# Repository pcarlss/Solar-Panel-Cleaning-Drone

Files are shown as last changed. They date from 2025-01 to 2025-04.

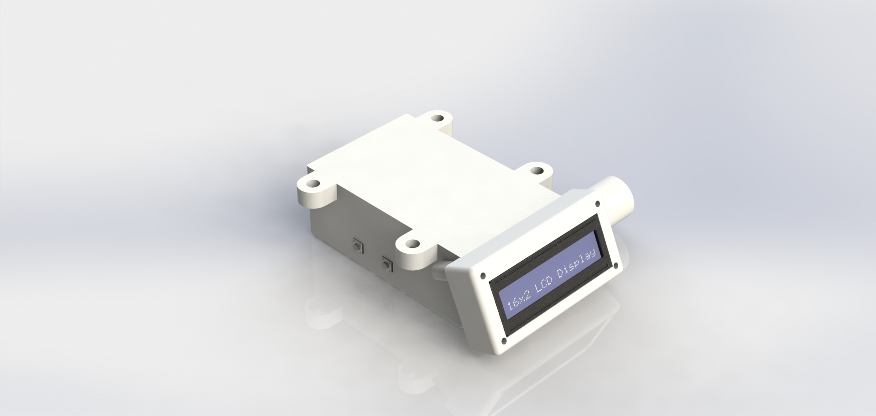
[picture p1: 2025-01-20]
FreeCad/mounting-assembly/Asmbly Render.JPG

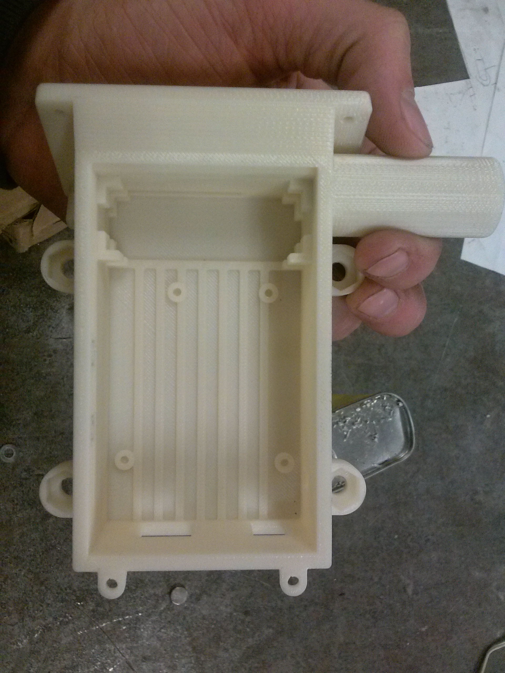
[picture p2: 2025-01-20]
FreeCad/mounting-assembly/Renderings/0404142058d.jpg

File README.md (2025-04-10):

# Solar Panel Cleaning Drone
Drone system developed by a team of 7 Concordia University students to transport and deploy a cleaning bot for efficient rooftop solar panel maintenance.

# Overview
This project is developed by a team of seven students from Concordia University, consisting of five Aerospace Engineering students and two Computer Engineering students. Our goal is to design and develop an autonomous system that utilizes a drone to transport and deploy a cleaning bot for rooftop solar panels. The drone delivers the cleaning bot to the rooftop, where it automatically cleans the solar panels, ensuring maximum efficiency by removing dust and debris. The project involves a combination of drone navigation, robotic automation, and sensor integration to create a fully autonomous cleaning solution.

# Members

## Aerospace Engineering
Our team of Aerospace Engineering students brings a wealth of knowledge and expertise to the project:
- **Aidan Mulrooney Gélinas**
- **Aysenur Kocak**
- **Nadim Zreik**
- **Oumaima Hida**
- **Raad Haider**

## Computer Engineering
Our Computer Engineering students are instrumental in the software and automation aspects:
- **Philip Carlsson-Coulombe**
- **Qian Yi Wang**

# Videos and Images
## Rover Simulation
rover_mission
## Drone Test Flight
ezgif-7473bbbd5976de (1)
## Cads
ISO_FINAL


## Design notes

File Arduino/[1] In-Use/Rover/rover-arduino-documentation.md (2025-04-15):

# Rover Arduino Documentation

## Pin Connection Guide

### Motor Pins
- Left Motor:
  - PWM: D9
  - Direction 1: D8
  - Direction 2: D7
- Right Motor:
  - PWM: D10
  - Direction 1: D11
  - Direction 2: D12
- Cleaning Motor:
  - Enable: D13

### Limit Switch Pins (CD4051B Multiplexer)
- Selector 0: D2
- Selector 1: D3
- Selector 2: D4
- Output: D5

### IMU (ICM-20948) I2C Pins
- SDA: A4
- SCL: A5

### Rotary Encoders
- Left Encoder:
  - Channel A: D2
  - Channel B: D3
- Right Encoder:
  - Channel A: D4
  - Channel B: D5

### Radio Control (nRF24L01)
- CE: D6
- CSN: D7

## Function Documentation

### Core Functions
- `setup()`: Initializes all hardware components including motors, encoders, IMU, and radio communication.
- `loop()`: Main program loop that handles state machine, sensor updates, and motor control.
- `updateData()`: Updates all sensor readings and system state.
- `updatePosition()`: Calculates current position based on encoder and IMU data.

### Motor Control
- `stopMotors()`: Stops all motors safely.
- `updateMotors()`: Updates motor speeds based on PID control.
- `setTrajectory(float linearVelocity, float turnRate)`: Sets desired linear velocity and turn rate.

### Sensor Management
- `getIMUData()`: Reads and processes IMU data.
- `performIMUCalibration()`: Performs IMU calibration sequence.
- `updateLimitSwitches()`: Updates limit switch states using multiplexer.
- `getLimitSwitchPositions()`: Returns current limit switch states.

### Encoder Functions
- `encoderISR_L()`: Interrupt service routine for left encoder.
- `encoderISR_R()`: Interrupt service routine for right encoder.
- `getLinearVelocity()`: Calculates current linear velocity from encoder data.

### Navigation Functions
- `makeDecision()`: Main decision-making function implementing the state machine.
- `searchForCorner()`: Implements corner search behavior.
- `cleanOuterLoop()`: Handles outer loop cleaning behavior.
- `cleanInnerLoops()`: Handles inner loop cleaning behavior.
- `followEdge()`: Implements edge following behavior.
- `followInnerPath()`: Implements inner path following behavior.

### Helper Functions
- `calculatePID()`: Implements PID control algorithm.
- `computeTravel()`: Calculates travel distance and direction.
- `mapInnerPath()`: Calculates inner cleaning path parameters.
- `calculateDistance()`: Calculates distance between two points.

## Setup Instructions

1. Hardware Setup:
   - Connect all motors to their respective pins
   - Connect limit switches through the CD4051B multiplexer
   - Connect IMU via I2C
   - Connect rotary encoders
   - Connect nRF24L01 radio module

2. Software Setup:
   - Install required libraries:
     - Wire.h (built-in)
     - PID_v1.h
     - ICM_20948.h
     - SPI.h (built-in)
     - nRF24L01.h
     - RF24.h

3. Calibration:
   - The system will automatically perform IMU calibration on startup
   - Keep the rover stationary during calibration
   - Calibration takes approximately 5 seconds

4. Operation:
   - Power on the rover
   - Wait for initialization to complete
   - Use the controller to start/stop the cleaning operation
   - The system will automatically handle the cleaning sequence

## Safety Features
- Emergency stop on radio signal loss
- Limit switch protection
- Motor current monitoring
- Automatic stop on error conditions

## Troubleshooting
1. If motors don't respond:
   - Check motor connections
   - Verify PWM pins are correctly connected
   - Check motor driver power supply

2. If IMU fails to initialize:
   - Check I2C connections
   - Verify IMU power supply
   - Ensure correct I2C address

3. If limit switches don't work:
   - Check multiplexer connections
   - Verify switch wiring
   - Test individual switches

4. If radio communication fails:
   - Check CE and CSN connections
   - Verify radio module power supply
   - Ensure correct address matching with controller

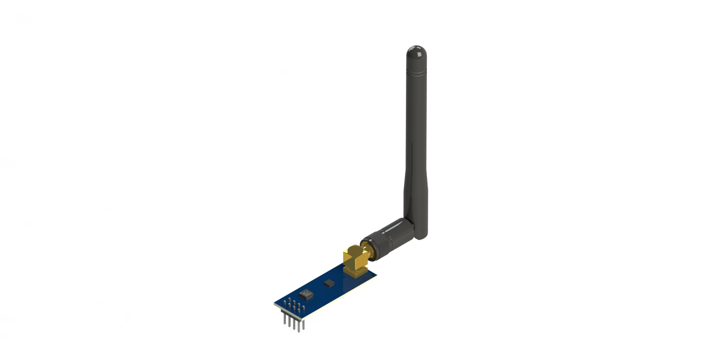
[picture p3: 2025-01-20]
FreeCad/nrf24l01/render/render.png

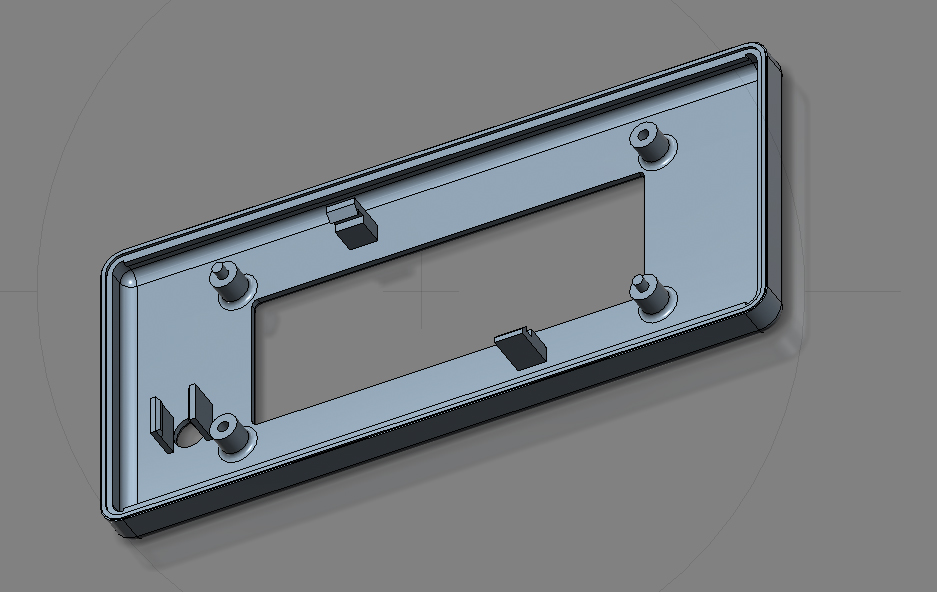
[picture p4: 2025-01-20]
FreeCad/1602_cover/Renderings/LCD_1602_box_03.jpg

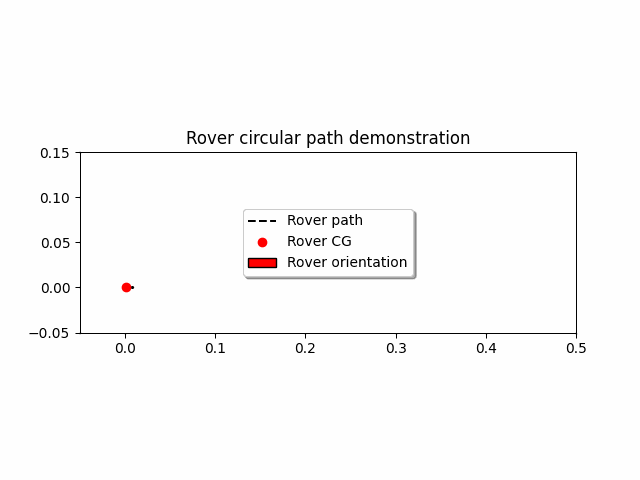
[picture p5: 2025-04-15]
Simulations/Rover-Simulation/movement.gif

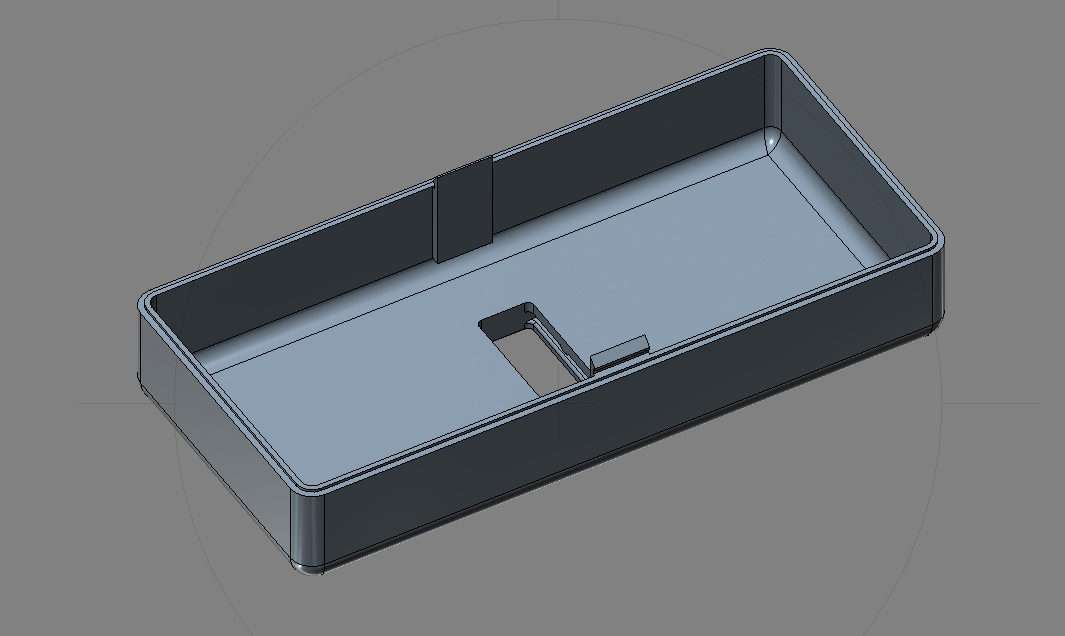
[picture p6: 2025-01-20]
FreeCad/1602_cover/Renderings/LCD_1602_box_04.jpg

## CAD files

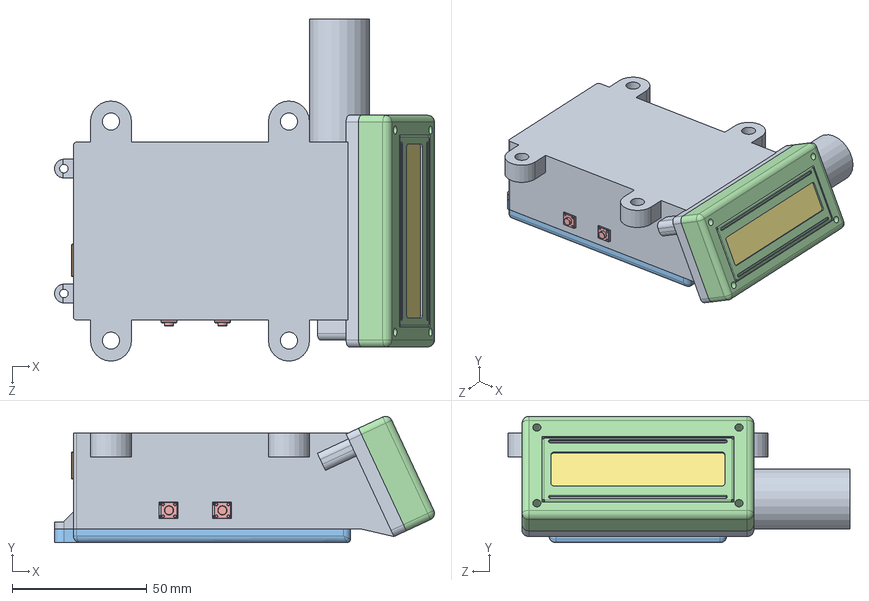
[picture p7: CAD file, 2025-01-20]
FreeCad/mounting-assembly/LCD and Arduino Mount ASMBLY.SLDASM
141.0 x 46.9 x 127.0 mm
Arduino Box
pcbboard
16pin_header__
lcd window
backlight
conductor x 2
liquid crystal grabcad
smt_resistor222 x 6
smt_resistor101 x 2
Arduino Box Lid
LCD Cover
tactileswitch-short x 2

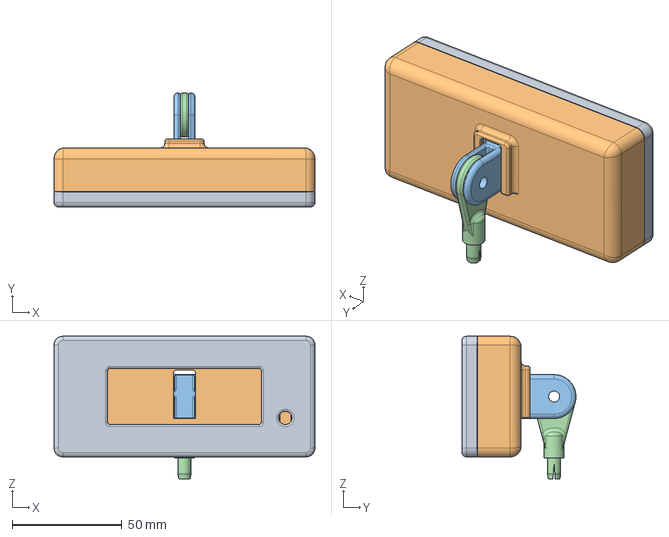
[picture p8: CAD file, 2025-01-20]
FreeCad/1602_cover/LCD-1602.stp
119.0 x 52.0 x 65.0 mm

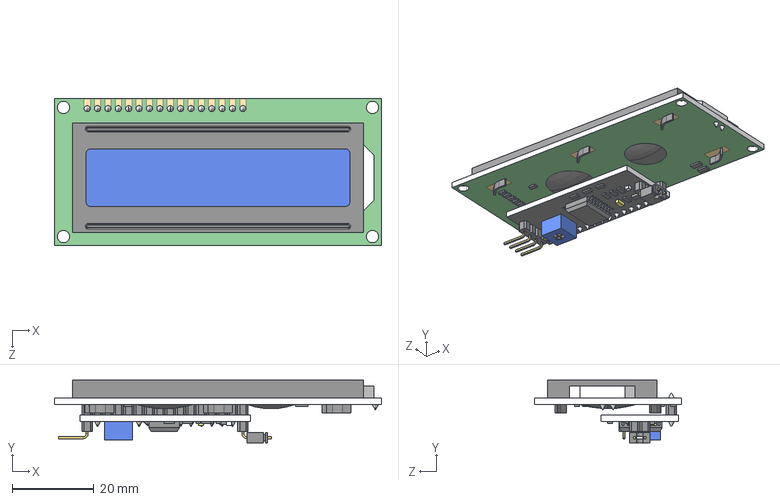
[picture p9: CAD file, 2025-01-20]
FreeCad/1602_model/LCD_I2C_1602.STEP
80.0 x 15.4 x 36.0 mm

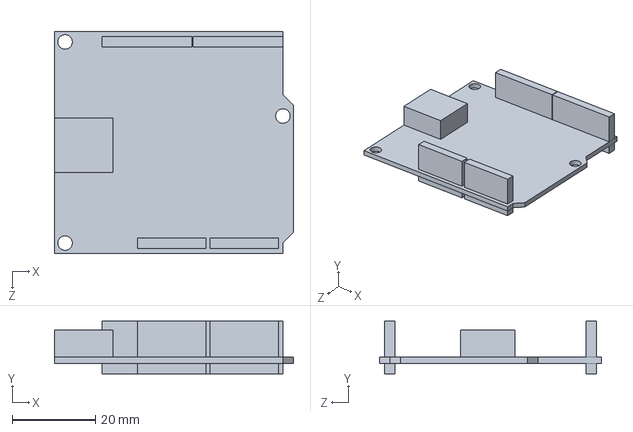
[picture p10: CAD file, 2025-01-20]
FreeCad/usb-host-shield/USBHostShield.SLDPRT
57.3 x 12.6 x 53.3 mm

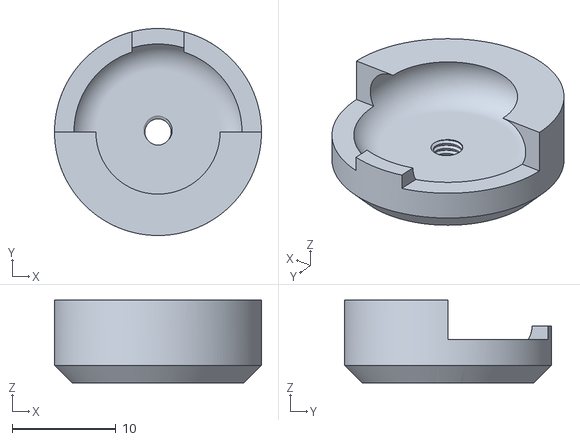
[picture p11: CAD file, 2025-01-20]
FreeCad/xbox-humbstick-extension/threaded_connector.stl
20.0 x 20.0 x 8.00

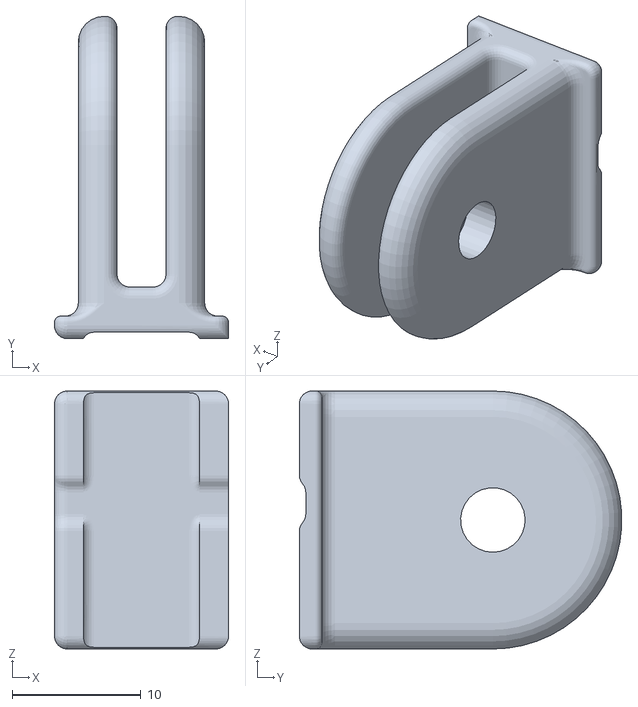
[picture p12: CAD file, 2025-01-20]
FreeCad/1602_cover/LCD-1602_holder-1.stl
13.5 x 25.0 x 20.0

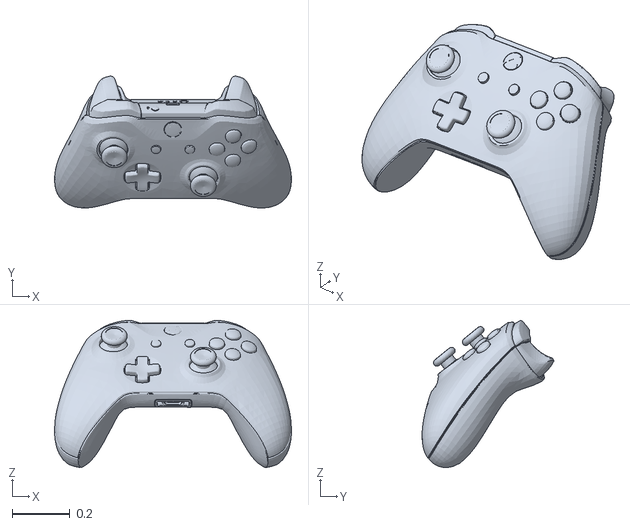
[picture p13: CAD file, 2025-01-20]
FreeCad/ImageToStl.com_white xbox controller.stl
0.824 x 0.459 x 0.512

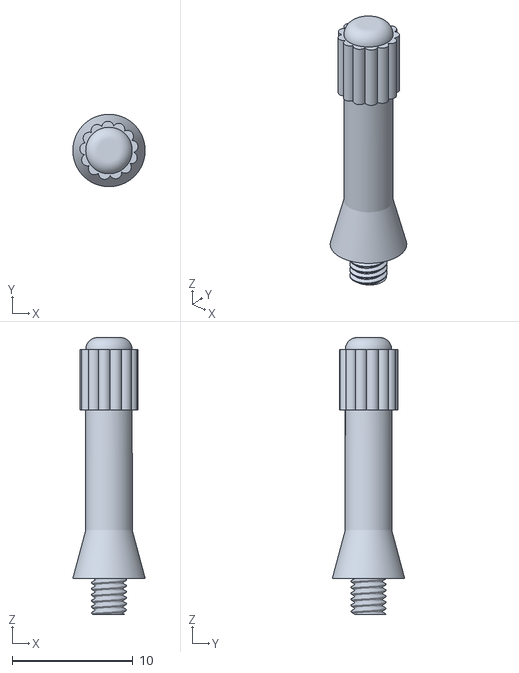
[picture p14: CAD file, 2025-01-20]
FreeCad/xbox-humbstick-extension/stick_short.stl
6.00 x 6.00 x 23.0

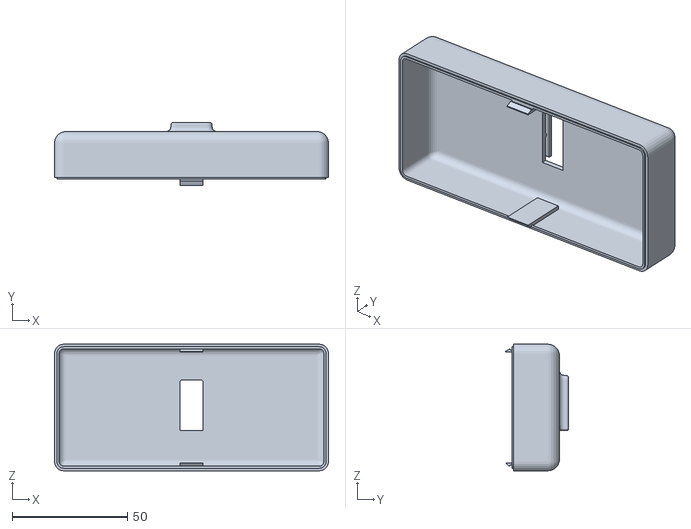
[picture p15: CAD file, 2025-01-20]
FreeCad/1602_cover/LCD-1602_back.stl
119.0 x 27.5 x 55.0

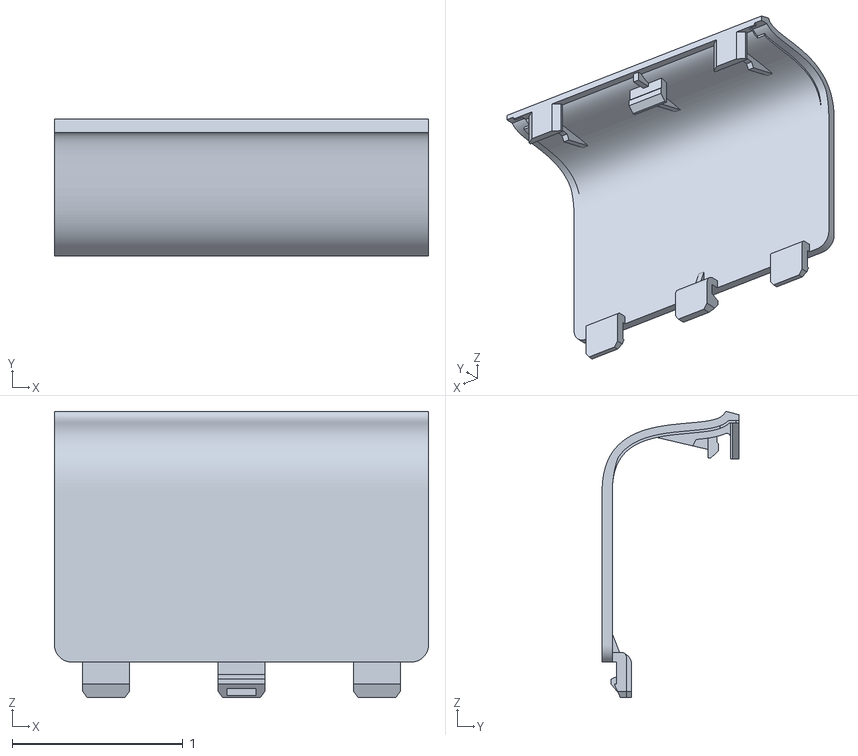
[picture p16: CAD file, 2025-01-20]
FreeCad/Xbox_One_Controller_Battery_Cover_-_Standard.stl
2.19 x 0.8 x 1.68

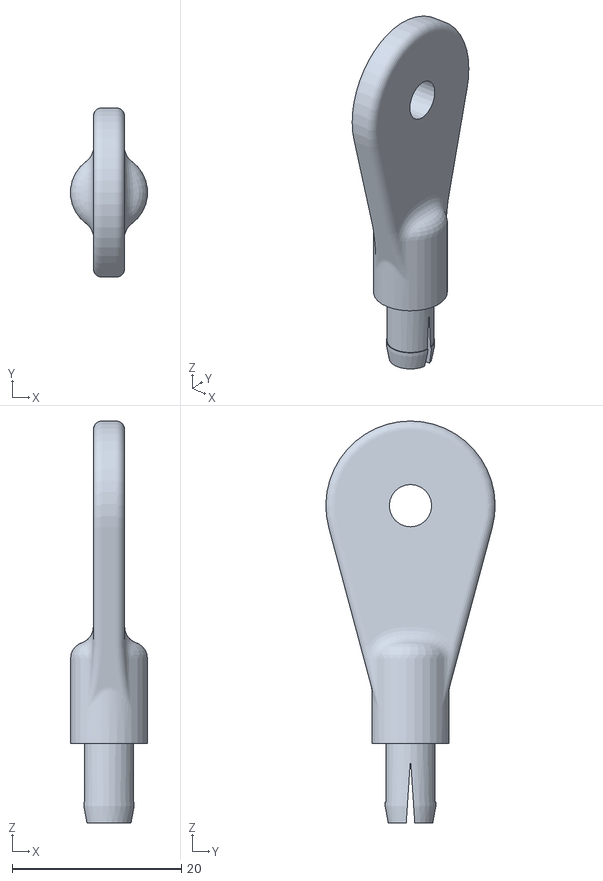
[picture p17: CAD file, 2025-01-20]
FreeCad/1602_cover/LCD-1602_holder-2.stl
9.07 x 20.0 x 47.5

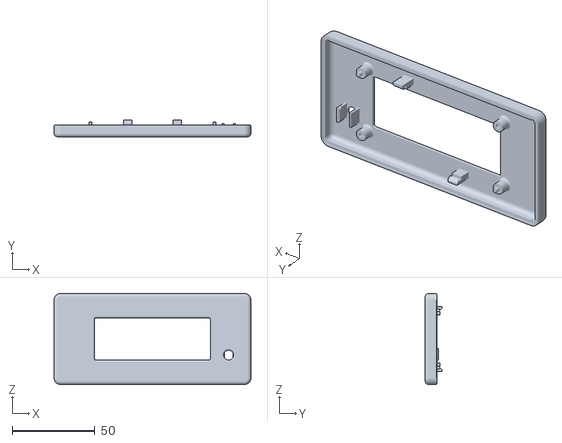
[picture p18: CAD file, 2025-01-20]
FreeCad/1602_cover/LCD-1602_front.stl
119.0 x 10.0 x 55.0

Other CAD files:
FreeCad/ControllerV1.FCStd
FreeCad/1602_cover/LCD-1602.f3d
FreeCad/1602_model/LCD_I2C_1602.SLDPRT

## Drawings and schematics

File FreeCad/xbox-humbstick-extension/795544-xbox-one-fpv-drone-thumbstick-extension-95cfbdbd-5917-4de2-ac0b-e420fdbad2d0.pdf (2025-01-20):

## Xbox One FPV Drone Thumbstick

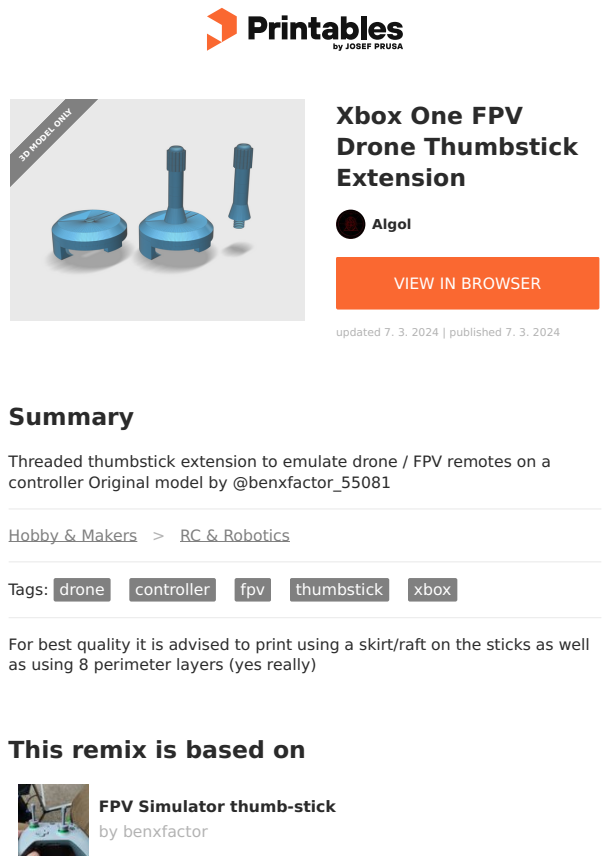
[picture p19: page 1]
Summary; Tags:; drone; controller; fpv; thumbstick; xbox; Algol; Extension; updated 7. 3. 2024 | published 7. 3. 2024; 3D MODEL ONLY

VIEW IN BROWSER (https://printables.com/model/795544-xbox-one-fpv-drone-thumbstick-extension)

Threaded thumbstick extension to emulate drone / FPV remotes on a
controller Original model by @benxfactor_55081

Hobby & Makers (https://printables.com/model?categoryId=48) > RC & Robotics (https://printables.com/model?categoryId=64)

For best quality it is advised to print using a skirt/raft on the sticks as well
as using 8 perimeter layers (yes really)

This remix is based on

FPV Simulator thumb-stick (https://printables.com/model/31084-fpv-simulator-thumb-stick)
by benxfactor (https://printables.com/@benxfactor_55081)

## Model files

## License

This work is licensed under a
Creative Commons (4.0 International License)

Attribution—Noncommercial—Share Alike (http://creativecommons.org/licenses/by-nc-sa/4.0/)

✖ | Sharing without ATTRIBUTION
✔ | Remix Culture allowed
✖ | Commercial Use
✖ | Free Cultural Works
✖ | Meets Open Definition

threaded_connector.stl

stick_short.stl

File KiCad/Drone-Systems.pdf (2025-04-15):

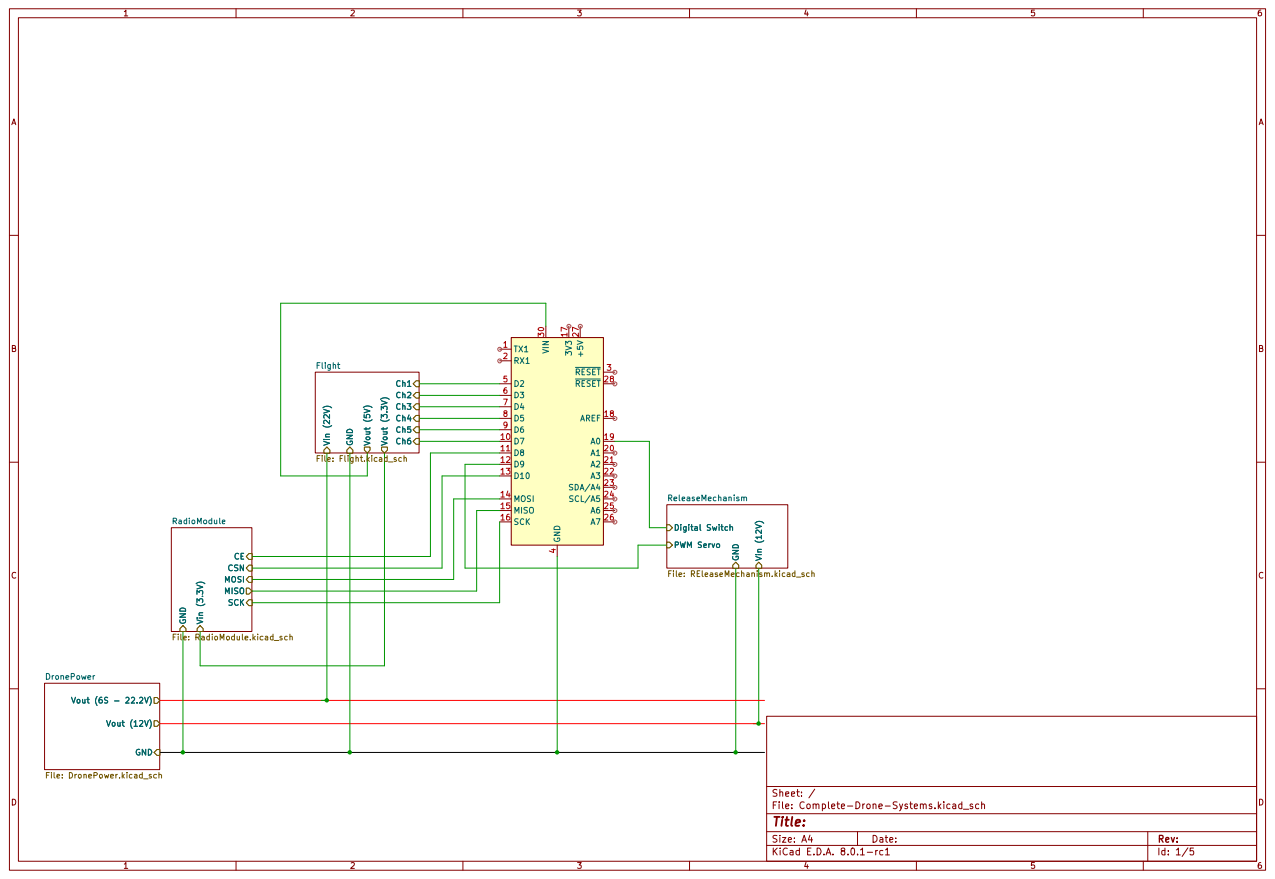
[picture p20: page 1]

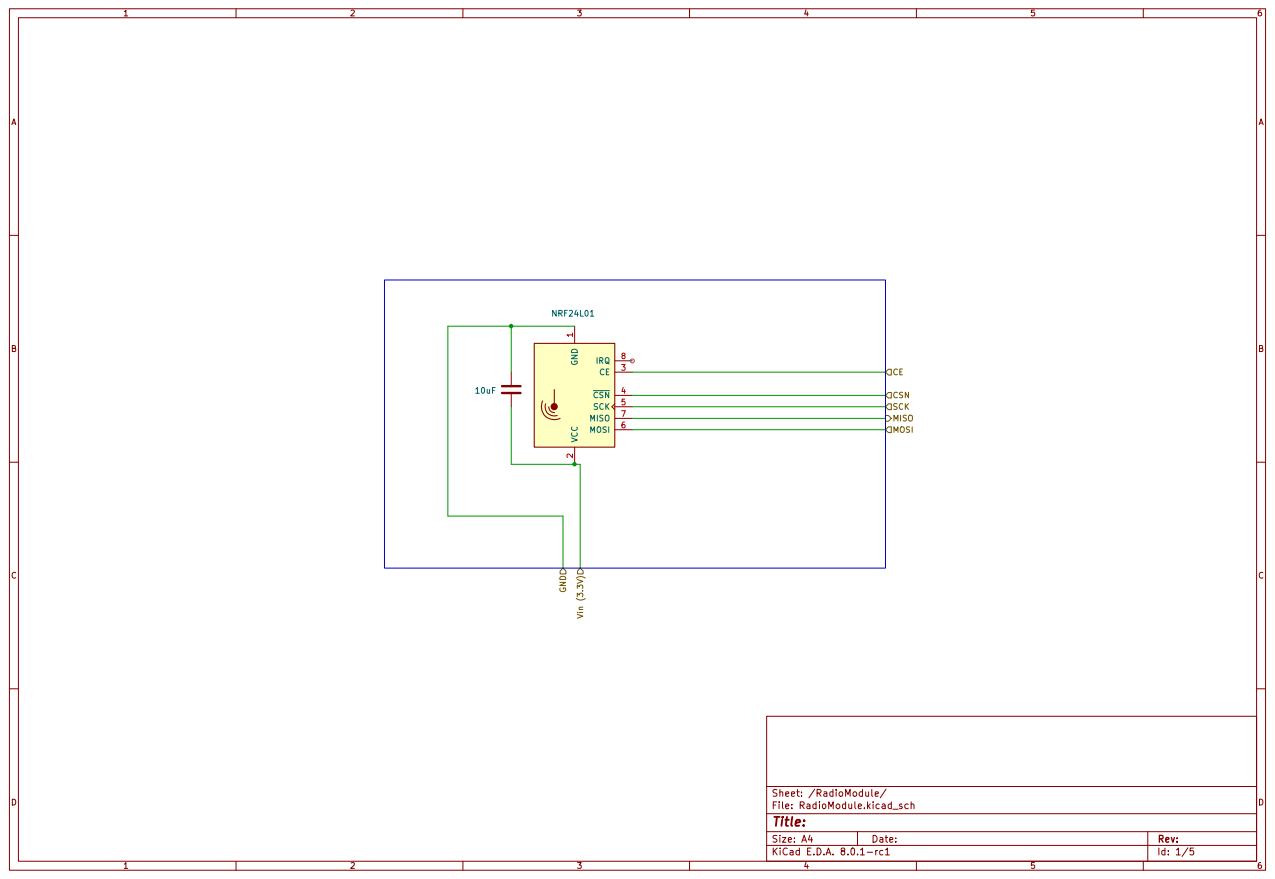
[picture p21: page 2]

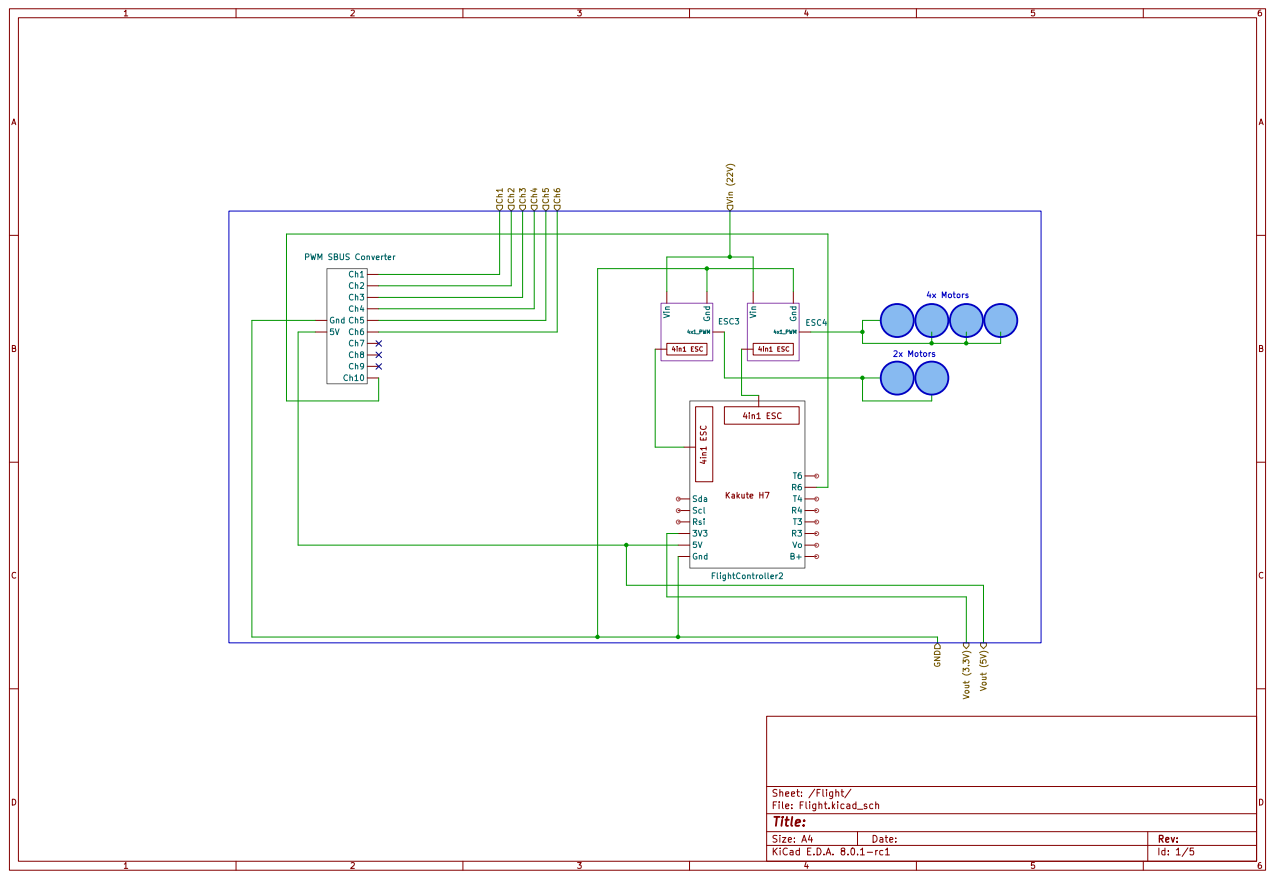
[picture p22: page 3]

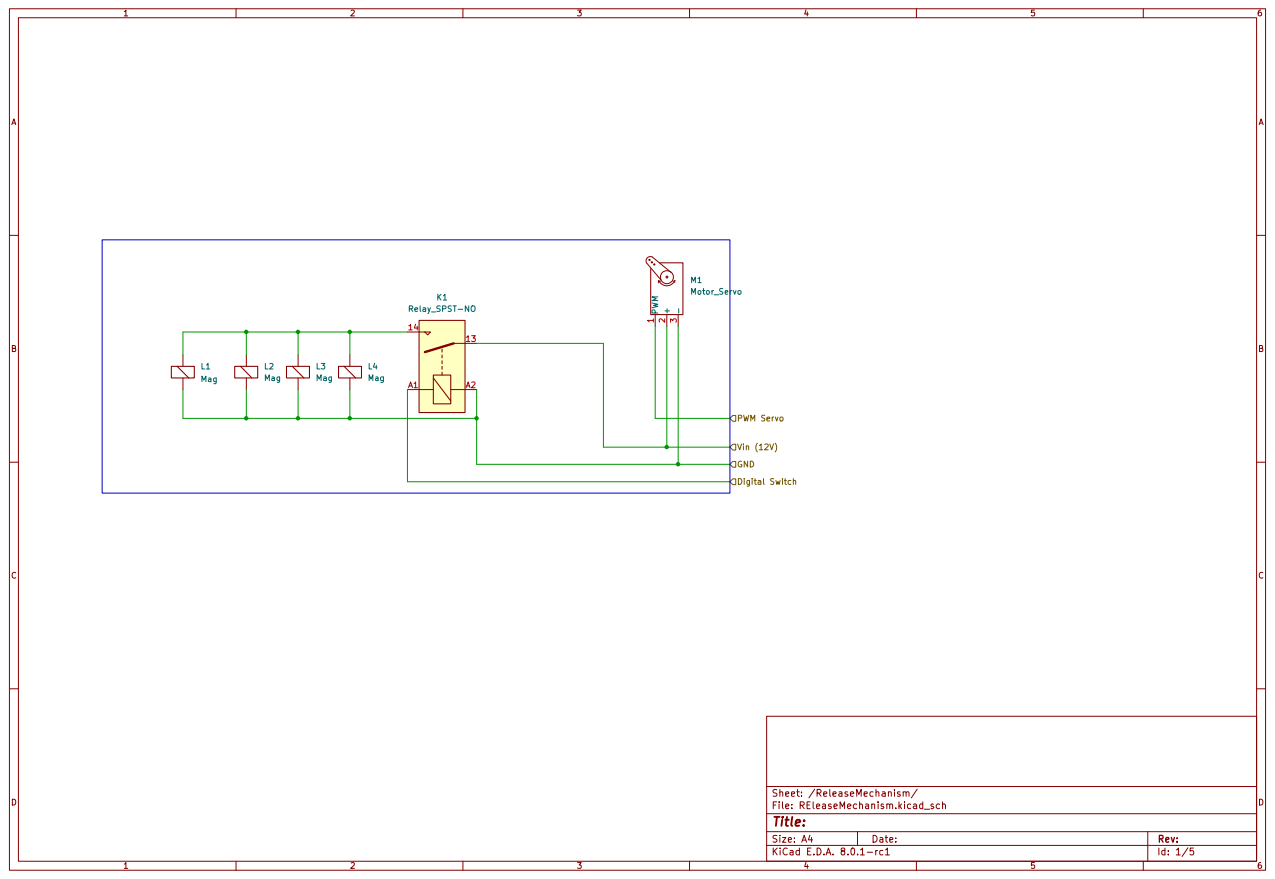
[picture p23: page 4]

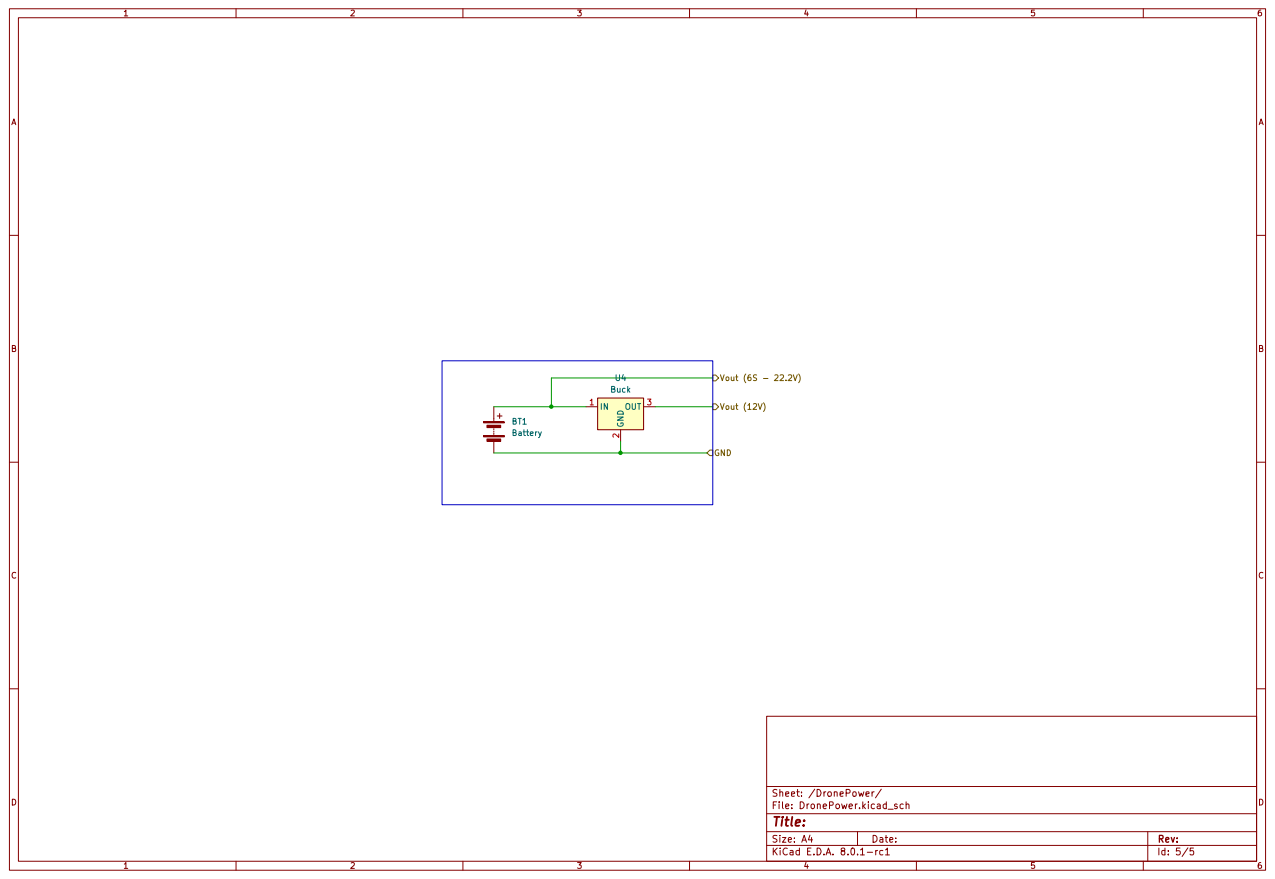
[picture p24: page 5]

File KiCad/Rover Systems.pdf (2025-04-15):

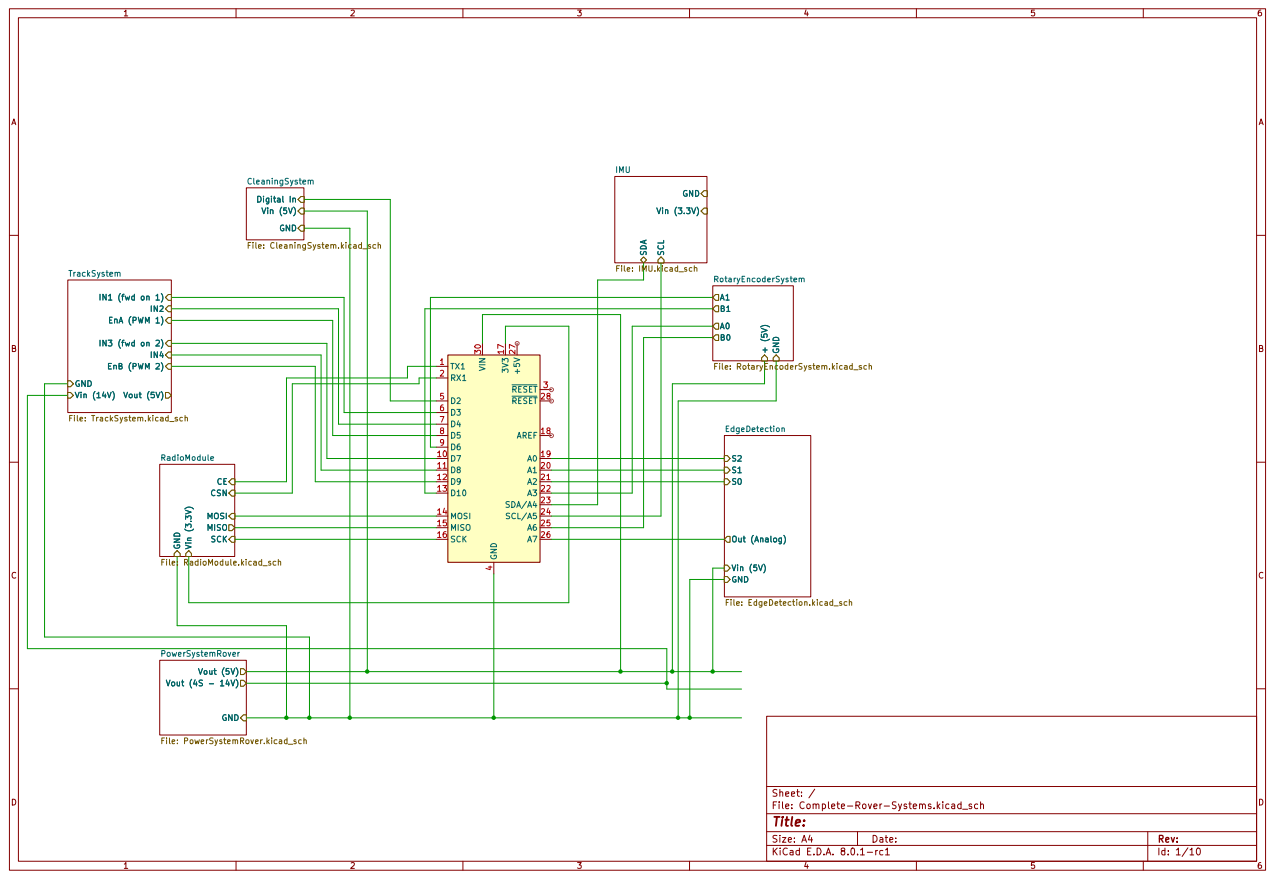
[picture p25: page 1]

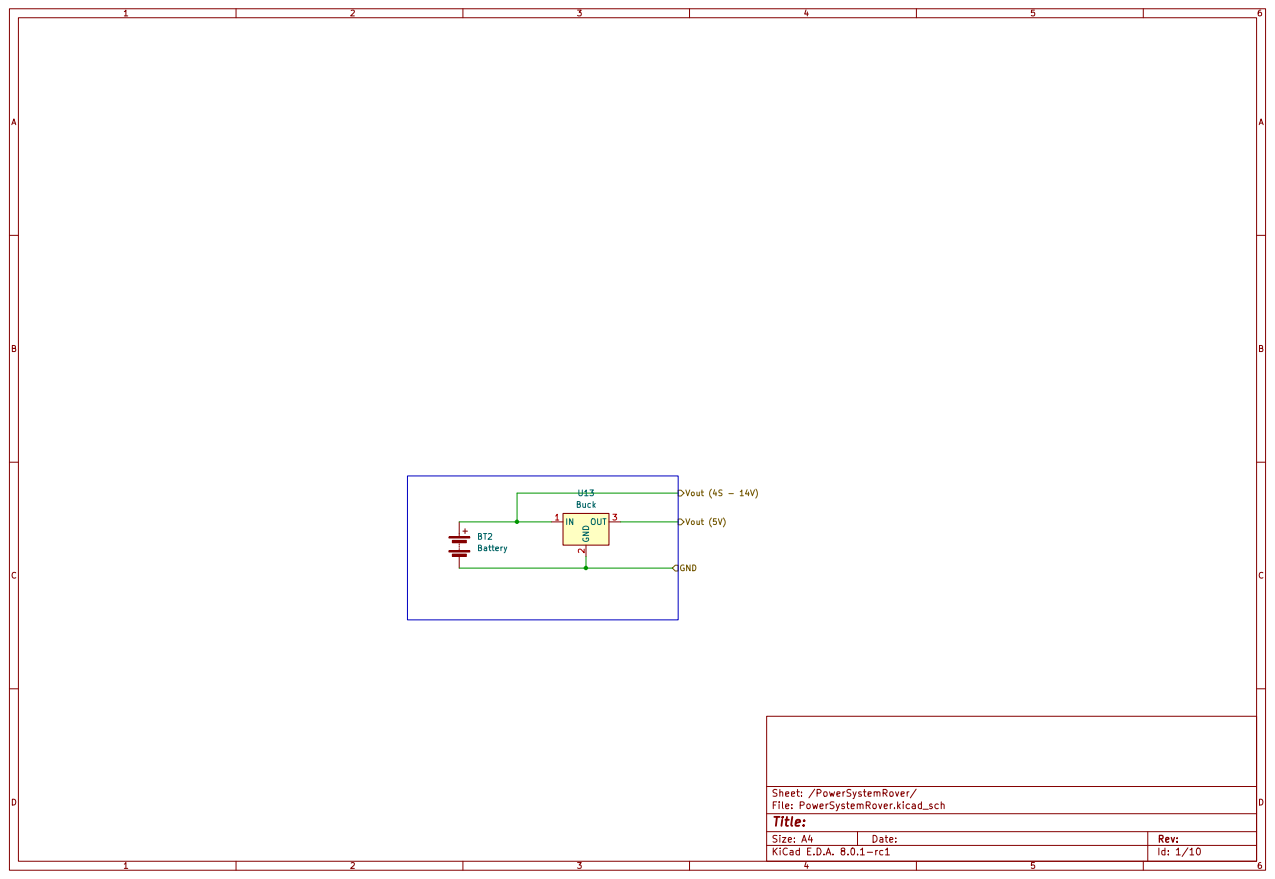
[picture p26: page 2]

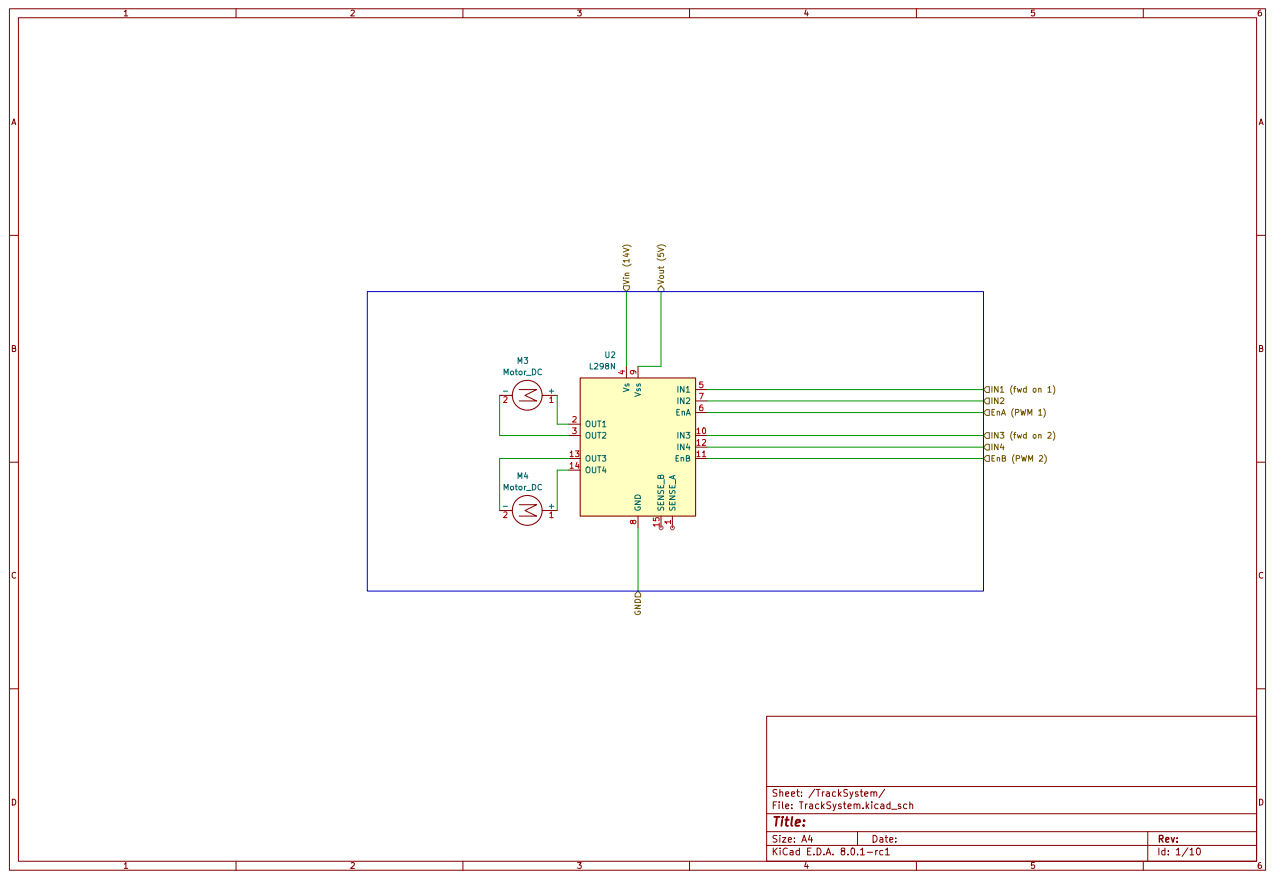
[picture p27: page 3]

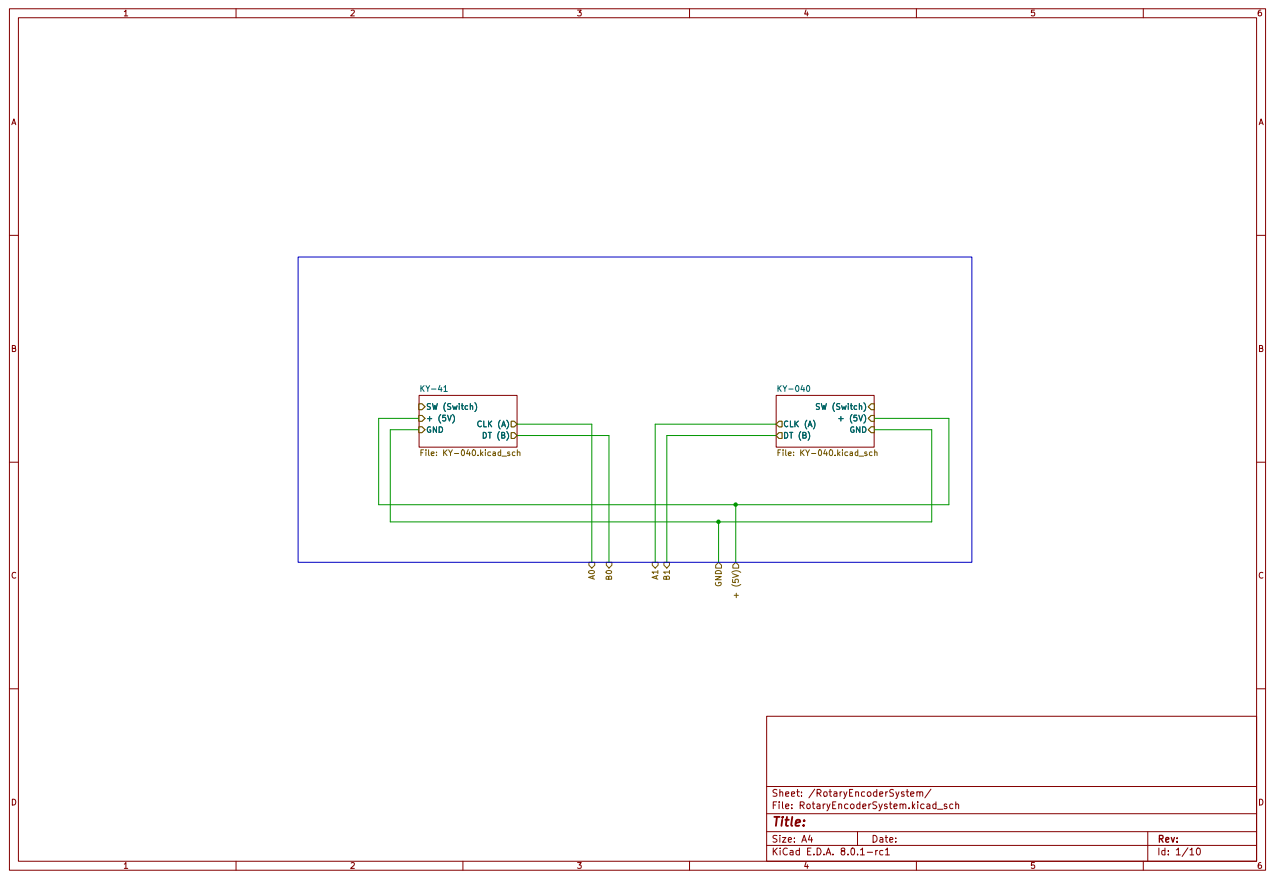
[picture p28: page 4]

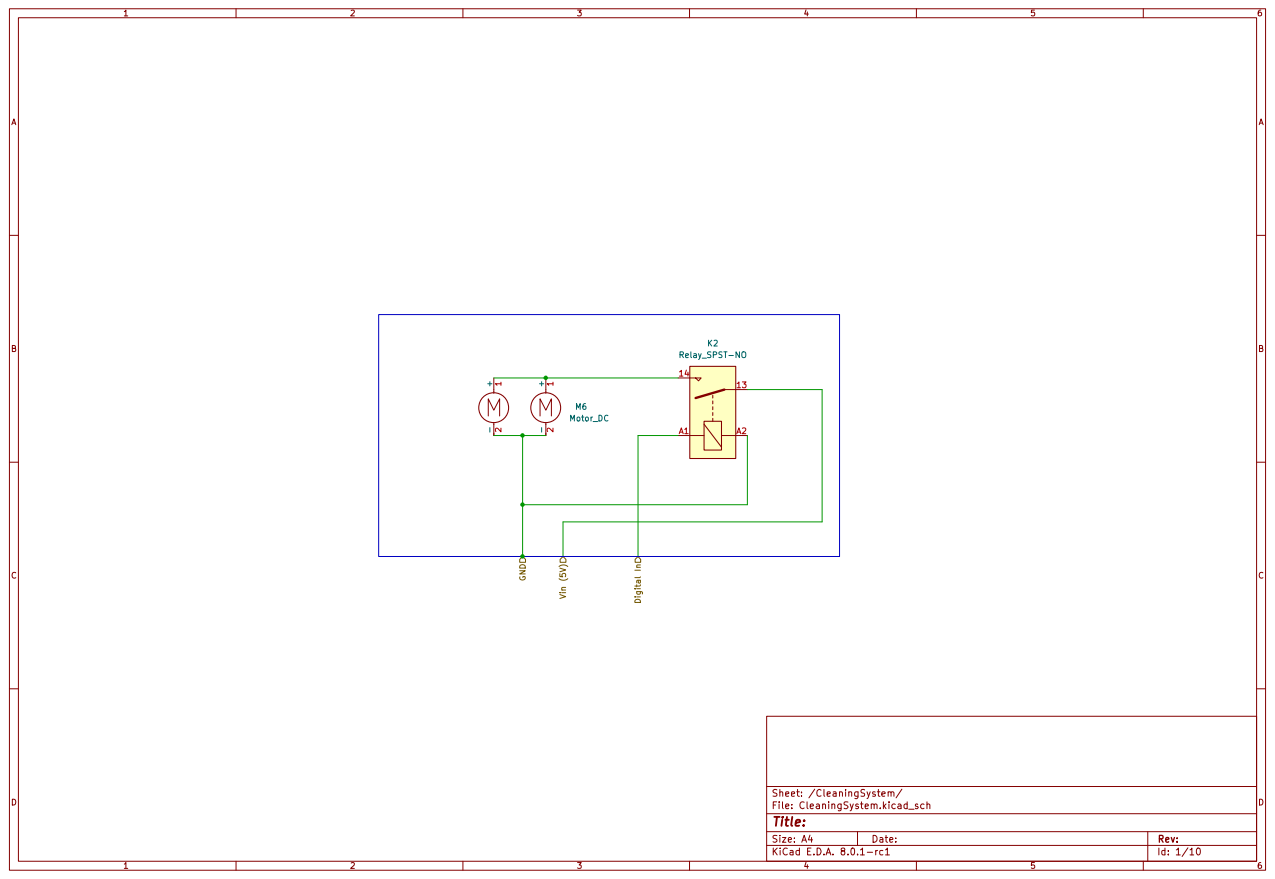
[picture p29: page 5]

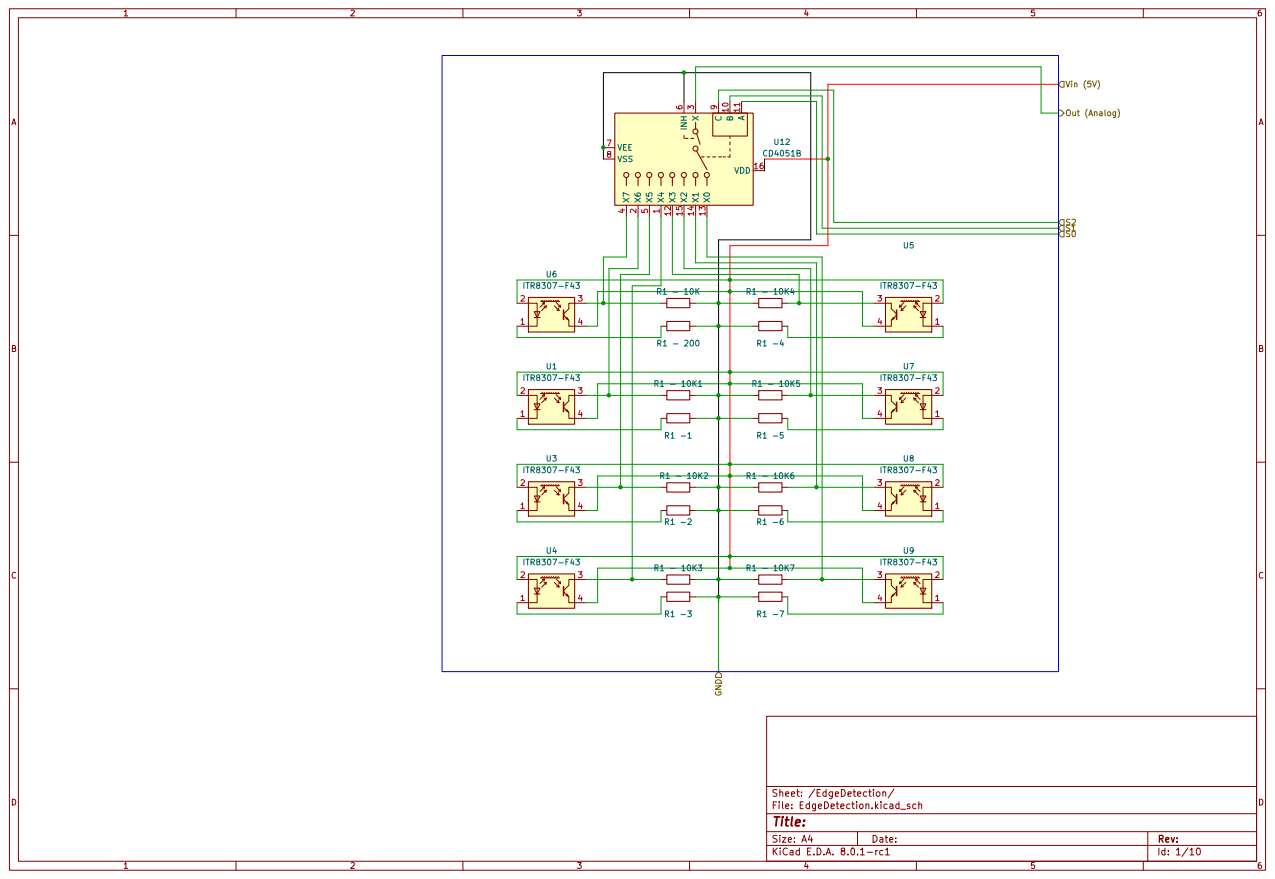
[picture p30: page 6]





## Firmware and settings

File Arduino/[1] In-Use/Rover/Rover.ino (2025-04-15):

#include <Wire.h>
#include <PID_v1.h>
#include <MPU6050.h>
#include <SPI.h>
#include <nRF24L01.h>
#include <RF24.h>
#include <SoftwareSerial.h>



//debug
bool SkipRadio = true;

// ==================== Pin Definitions ====================
// Motor pins
#define MOTOR_L_PWM 5    // D5 - Left motor PWM (EN_A)
#define MOTOR_L_IN1 4    // D4 - Left motor direction 1
#define MOTOR_L_IN2 A1   // A1 - Left motor direction 2
#define MOTOR_R_PWM 6    // D6 - Right motor PWM (EN_B)
#define MOTOR_R_IN1 8    // D8 - Right motor direction 1
#define MOTOR_R_IN2 7    // D7 - Right motor direction 2
#define CLEANING_MOTOR_ENABLE 13  // D13 - Cleaning motor enable

// ESP32 Serial Communication
SoftwareSerial espSerial(A0, 255);  // RX = A0, TX unused (changed from D8 to avoid conflict)
bool LFO, RFI, RFO, LBO, LFI, RBO, LBI, RBI;  // Limit switch states

// Limit switch count
#define LIMIT_SWITCH_COUNT 8


// IMU pins
#define IMU_SDA A4  // A4 - IMU I2C data
#define IMU_SCL A5  // A5 - IMU I2C clock

// Encoder pins
#define ENCODER_L_A 2    // D2 - Left encoder channel A (interrupt)
#define ENCODER_L_B 3    // D3 - Left encoder channel B (interrupt)
#define ENCODER_R_A A0   // A0 - Right encoder channel A
#define ENCODER_R_B A1   // A1 - Right encoder channel B

// Radio pins
#define CE_PIN 6    // D6 - Radio CE pin
#define CSN_PIN 7   // D7 - Radio CSN pin

// ==================== Constants ====================
// Physical constants
const float AXLE_LENGTH = 0.170;  // 170mm
const float WHEEL_RADIUS = 0.025; // 25mm
const float TOP_VOLTAGE = 12;     // 12 V
const float TOP_SPEED = 0.08;     // 8 cm/s
const float TOP_TURN_RATE = 1.0;  // rad/s
const float MIN_ANGLE = 0.31415926535;      // Minimum angle change for velocity calculation
const float ZERO_TIME = 0.5;      // Time in seconds before zeroing velocity

// IMU Configuration
#define SAMPLE_RATE 100  // Hz
#define CALIBRATION_SAMPLES 250
#define VALIDATION_SAMPLES 100
#define STABILITY_THRESHOLD 0.1  // degrees/s for gyro, mg for accel
#define MPU 0x68  // MPU6050 I2C address

// Add IMU error variables
float AccErrorX, AccErrorY, GyroErrorX, GyroErrorY, GyroErrorZ;
float accAngleX, accAngleY, gyroAngleX, gyroAngleY, gyroAngleZ;
float roll, pitch, yaw;
float elapsedTime, currentTime, previousTime;

// Add lockout constant after other constants
#define LOCKOUT_COUNTDOWN 20  // Matches simulation

// Add debounce constant after other constants
#define ENCODER_DEBOUNCE_TIME 10  // Minimum time between readings in ms

// Add MIN_TIME constant after other constants
#define MIN_TIME 20  // Define MIN_TIME as needed

// ==================== Type Definitions ====================
// Enums for state management
enum DecisionStates { IDLE, SEARCHFORCORNER, BEGINCLEANING, CLEANOUTERLOOP, CLEANINNERLOOPS, DONE };
enum SearchForCornerStates { MOVEBACKWARDSUNTILEDGE, ALIGNWITHEDGE, TURNRIGHT, ADJUSTBACKANDFORTH, MOVEBACKWARDSUNTILCORNER, SEARCHDONE };
enum OuterLoopStates { FOLLOWEDGE, TURNLEFT, OUTERDONE };
enum InnerLoopStates { FOLLOWINNERPATH, TURNLEFTINNER, INNERDONE };
enum RadioMessage { NOMESSAGE, STARTCLEANINGOK, CLEANINGDONETAKEMEAWAY, ERROR };

// Structs
struct Point {
    float x;
    float y;
};

struct PositionalInformation {
    float position[2];      // [x, y]
    float orientation[2];   // [x, y] unit vector
    float azimuth;         // Current heading angle
    float linear_velocity; // Current linear velocity
    float turn_rate;      // Current turn rate
    float linear_accel;   // Current linear acceleration
    float turn_accel;     // Current turn acceleration
    float l_speed;        // Left wheel speed
    float r_speed;        // Right wheel speed
};

struct SensorData {
    float accelX, accelY, accelZ;
    float gyroX, gyroY, gyroZ;
    long leftEncoder, rightEncoder;
    long leftEncoderVelocity, rightEncoderVelocity;
    float lastPosition = 0.0, imuVelocity = 0.0, imuPosition = 0.0;    
};

struct IMUData {
    float accel[3];    // [x, y, z] acceleration in m/s²
    float gyro[3];     // [x, y, z] angular velocity in rad/s
    float orientation[3]; // [roll, pitch, yaw] in radians
    float accelBias[3];
    float gyroBias[3];
    bool isCalibrated;
};

struct ControllerData {
  int roll;
  int pitch;
  int throttle;
  int yaw;
  int angle;
  int safety;
  bool AUX;
};

// ==================== Global Variables ====================
// State variables
DecisionStates decisionState = IDLE;
SearchForCornerStates searchForCornerState = MOVEBACKWARDSUNTILEDGE;
OuterLoopStates outerLoopState = FOLLOWEDGE;
InnerLoopStates innerLoopState = FOLLOWINNERPATH;
RadioMessage radioMessage = NOMESSAGE;

// Motor control variables
int l_speed = 0;
int r_speed = 0;

// PID control variables
double pidInputL, pidOutputL, pidSetpointL;
double pidInputR, pidOutputR, pidSetpointR;
double pidKp = 0.05;  // Proportional gain
double pidKi = 0.5;   // Integral gain
double pidKd = 0.05;  // Derivative gain
double pidKff = 3.0;  // Feed-forward gain

// Add after other PID variables
double posKp = 0.25;  // Position proportional gain
double posKi = 0.05;  // Position integral gain
double posKd = 0.0;   // Position derivative gain
double oriKp = 0.8;   // Orientation proportional gain
double oriKi = 0.0;   // Orientation integral gain
double oriKd = 0.0;   // Orientation derivative gain
double posPidInput, posPidOutput, posPidSetpoint;
double oriPidInput, oriPidOutput, oriPidSetpoint;
PID pidPosition(&posPidInput, &posPidOutput, &posPidSetpoint, posKp, posKi, posKd, DIRECT);
PID pidOrientation(&oriPidInput, &oriPidOutput, &oriPidSetpoint, oriKp, oriKi, oriKd, DIRECT);

// Encoder variables
const int numReadings = 20;
float readingsL[numReadings] = {0};
float readingsR[numReadings] = {0};
int indexL = 0;
int indexR = 0;
bool filledL = false;
bool filledR = false;

volatile float leftEncoderVelocity = 0.0;
volatile float rightEncoderVelocity = 0.0;
volatile long timeBetweenL = 0;
volatile long timeBetweenR = 0;
volatile short prevStepL = 0;
volatile short prevStepR = 0;
volatile unsigned long previousTimeL = millis();
volatile unsigned long previousTimeR = millis();

// Timing variables
unsigned long lastTime = 0;
unsigned long lastUpdateTime = 0;
unsigned long lastEncoderTime = 0;
unsigned long lastIMUTime = 0;
unsigned long lastSignalTime = 0;

// Panel mapping variables
Point cornerLocations[5];
int cornerCount = 0;
float panelHeight = 0;
float panelWidth = 0;
float desiredDistance = 0;
float desiredAzimuth = 0;
String cleaningAxis = "height";
int panelHeightNodes = 0;
int panelWidthNodes = 0;

// Radio variables
RF24 radio(CE_PIN, CSN_PIN);
const byte address[6] = "00001";
bool radioInitialized = false;
bool signalLost = false;
ControllerData receivedData;

// Sensor objects and data
MPU6050 mpu;
IMUData imuData;
SensorData sensorData;
PositionalInformation currentPosition;
PositionalInformation estimatedPosition;
PID pidLeft(&pidInputL, &pidOutputL, &pidSetpointL, pidKp, pidKi, pidKd, DIRECT);
PID pidRight(&pidInputR, &pidOutputR, &pidSetpointR, pidKp, pidKi, pidKd, DIRECT);

// Add lockout variable to global variables section
int lockoutCountdown = 0;

// ==================== Function Prototypes ====================
// Core functions
void updateData();
void updatePosition();
void makeDecision();

// Motor control functions
void stopMotors();
void updateMotors();
void setTrajectory(float linearVelocity, float turnRate);

// Sensor functions
void getIMUData();
void performIMUCalibration();
void updateLimitSwitches();

// Navigation functions
void searchForCorner();
void moveBackwardUntilEdge();
void alignWithEdge();
void turnRight(int deg);
void turnLeft(int deg);
void adjustBackAndForth();
void moveBackwardUntilCorner();
void followEdge();
void followInnerPath();
void initializeCleaning();
void cleanOuterLoop();
void cleanInnerLoops();
void whenDone();

// Helper functions
float getLinearVelocity();
void computeTravel(float linear_velocity, float turn_rate, float deltaTime);
bool checkLimitSwitches();
float getCurrentAzimuth();
void updatePositionalTrajectory();
void updateTurningTrajectory();
float calculatePID(float setpoint, float input);
void mapInnerPath();
float calculateDistance(Point p1, Point p2);

// Interrupt handlers
void encoderISR_L();
void encoderISR_R();

// Encoder Reading Functions
float getLeftEncoderVelocity();
float getAvgLeftEncoderVelocity();
float getRightEncoderVelocity();
float getAvgRightEncoderVelocity();

// ==================== Setup and Main Loop ====================
void setup() {
    // Initialize serial communication
    Serial.begin(115200);
    espSerial.begin(38400);  // Initialize communication with ESP32
    
    while (!Serial) {
      Serial.println("no serial");
    }


    Serial.println("mpu init");

    // Initialize IMU
    Wire.begin();
    
    // Configure MPU6050
    Wire.beginTransmission(MPU);
    Wire.write(0x6B);  // PWR_MGMT_1 register
    Wire.write(0x00);  // Set to zero to wake up
    Wire.endTransmission(true);
    
    // Configure Accelerometer Sensitivity - Full Scale Range (+/- 8g)
    Wire.beginTransmission(MPU);
    Wire.write(0x1C);  // ACCEL_CONFIG register
    Wire.write(0x10);  // Set to 0x10 for +/- 8g
    Wire.endTransmission(true);
    
    // Configure Gyro Sensitivity - Full Scale Range (1000deg/s)
    Wire.beginTransmission(MPU);
    Wire.write(0x1B);  // GYRO_CONFIG register
    Wire.write(0x10);  // Set to 0x10 for 1000deg/s
    Wire.endTransmission(true);
    
    delay(20);
    
    // Calculate IMU error values
    calculate_IMU_error();
    delay(20);

    // Initialize radio
    if(SkipRadio){
        Serial.println("skip radio");
        decisionState = SEARCHFORCORNER;
    }
    else if (!radio.begin()) {
        // Radio hardware not responding
        while (1); // Stop if radio fails
        
    }else{
        radio.openReadingPipe(0, address);
        radio.setAutoAck(false);
        radio.setDataRate(RF24_1MBPS);
        radio.setPALevel(RF24_PA_MIN);
        radio.setPayloadSize(sizeof(ControllerData));
        radio.setChannel(100);
        radio.startListening();
        
        radioInitialized = true;
    }
    
    

    // Initialize other pins
    pinMode(MOTOR_L_PWM, OUTPUT);
    pinMode(MOTOR_L_IN1, OUTPUT);
    pinMode(MOTOR_L_IN2, OUTPUT);
    pinMode(MOTOR_R_PWM, OUTPUT);
    pinMode(MOTOR_R_IN1, OUTPUT);
    pinMode(MOTOR_R_IN2, OUTPUT);

    pinMode(ENCODER_L_A, INPUT_PULLUP);
    pinMode(ENCODER_L_B, INPUT_PULLUP);
    pinMode(ENCODER_R_A, INPUT_PULLUP);
    pinMode(ENCODER_R_B, INPUT_PULLUP);

    attachInterrupt(digitalPinToInterrupt(ENCODER_L_A), encoderISR_L, CHANGE);
    attachInterrupt(digitalPinToInterrupt(ENCODER_R_A), encoderISR_R, CHANGE);

    pidLeft.SetMode(AUTOMATIC);
    pidRight.SetMode(AUTOMATIC);
    pidPosition.SetMode(AUTOMATIC);
    pidOrientation.SetMode(AUTOMATIC);
    pidLeft.SetOutputLimits(-TOP_VOLTAGE, TOP_VOLTAGE);
    pidRight.SetOutputLimits(-TOP_VOLTAGE, TOP_VOLTAGE);
    pidPosition.SetOutputLimits(-TOP_SPEED, TOP_SPEED);
    pidOrientation.SetOutputLimits(-TOP_TURN_RATE, TOP_TURN_RATE);

    Serial.println("setup done");
}

void loop() {
    Serial.println("loopin?");
    // Check for radio signals
    if(SkipRadio){
      //
    }
    else if (radio.available()) {
        lastSignalTime = millis();
        signalLost = false;
        radio.read(&receivedData, sizeof(receivedData));
        
        // Handle start/stop signals
        if (receivedData.AUX) {
            // Start signal received
            if (decisionState == IDLE) {
                decisionState = SEARCHFORCORNER;
                searchForCornerState = MOVEBACKWARDSUNTILEDGE;
            }
        } else {
            // Stop signal received
            if (decisionState != IDLE) {
                decisionState = IDLE;
                stopMotors();
            }
        }
    } else {
        // Check for signal loss
        if (millis() - lastSignalTime > 50) {
            if (!signalLost) {
                signalLost = true;
            }
            // Emergency stop on signal loss
            if (decisionState != IDLE) {
                decisionState =  IDLE;
                stopMotors();
            }
        }
    }
    Serial.println("loopin?");
    updateData();
    updatePosition();
    makeDecision();
    
    // Inner loop state machine
    switch (innerLoopState) {
        case FOLLOWINNERPATH:
            followInnerPath();
            break;
        case TURNLEFTINNER:
            turnLeft(90);
            break;
        case DONE:
            // Inner loop complete, move to next state
            decisionState = DONE;
            break;
    }
}

// ==================== Function Implementations ====================
// Core functions
void updateData() {
    // Update IMU data
    getIMUData();
    
    // Update limit switch states
    updateLimitSwitches();

    
    // Update sensor data structure
    sensorData.accelX = imuData.accel[0];
    sensorData.accelY = imuData.accel[1];
    sensorData.accelZ = imuData.accel[2];
    sensorData.gyroX = imuData.gyro[0];
    sensorData.gyroY = imuData.gyro[1];
    sensorData.gyroZ = imuData.gyro[2];
    
    // Update encoder data
    sensorData.leftEncoderVelocity = getAvgLeftEncoderVelocity();
    sensorData.rightEncoderVelocity = getAvgRightEncoderVelocity();
    
    // Update IMU-based position and velocity
    sensorData.imuVelocity = sqrt(imuData.accel[0] * imuData.accel[0] + 
                                 imuData.accel[1] * imuData.accel[1]);
    sensorData.imuPosition = currentPosition.position[0]; // Using x position as example
}

void calculate_IMU_error() {
    Serial.println("calculating mpu error");
    int c = 0;
    
    // Read accelerometer values 200 times
    while (c < 200) {
        Wire.beginTransmission(MPU);
        Wire.write(0x3B);
        Wire.endTransmission(false);
        Wire.requestFrom(MPU, 6, true);
        float AccX = (Wire.read() << 8 | Wire.read()) / 16384.0;
        float AccY = (Wire.read() << 8 | Wire.read()) / 16384.0;
        float AccZ = (Wire.read() << 8 | Wire.read()) / 16384.0;
        
        // Sum all readings
        AccErrorX = AccErrorX + ((atan((AccY) / sqrt(pow((AccX), 2) + pow((AccZ), 2))) * 180 / PI));
        AccErrorY = AccErrorY + ((atan(-1 * (AccX) / sqrt(pow((AccY), 2) + pow((AccZ), 2))) * 180 / PI));
        c++;
    }
    
    //Divide the sum by 200 to get the error value
    AccErrorX = AccErrorX / 200;
    AccErrorY = AccErrorY / 200;
    c = 0;
    
    // Read gyro values 200 times
    while (c < 200) {
        Wire.beginTransmission(MPU);
        Wire.write(0x43);
        Wire.endTransmission(false);
        Wire.requestFrom(MPU, 6, true);
        float GyroX = Wire.read() << 8 | Wire.read();
        float GyroY = Wire.read() << 8 | Wire.read();
        float GyroZ = Wire.read() << 8 | Wire.read();
        
        // Sum all readings
        GyroErrorX = GyroErrorX + (GyroX / 131.0);
        GyroErrorY = GyroErrorY + (GyroY / 131.0);
        GyroErrorZ = GyroErrorZ + (GyroZ / 131.0);
        c++;
    }
    
    //Divide the sum by 200 to get the error value
    GyroErrorX = GyroErrorX / 200;
    GyroErrorY = GyroErrorY / 200;
    GyroErrorZ = GyroErrorZ / 200;
}

void getIMUData() {
    // Read accelerometer data
    Wire.beginTransmission(MPU);
    Wire.write(0x3B);  // Start with register 0x3B (ACCEL_XOUT_H)
    Wire.endTransmission(false);
    Wire.requestFrom(MPU, 6, true);
    
    // Convert raw values to actual acceleration in g
    imuData.accel[0] = (Wire.read() << 8 | Wire.read()) / 16384.0;  // X-axis
    imuData.accel[1] = (Wire.read() << 8 | Wire.read()) / 16384.0;  // Y-axis
    imuData.accel[2] = (Wire.read() << 8 | Wire.read()) / 16384.0;  // Z-axis
    
    // Calculate angles from accelerometer
    accAngleX = (atan(imuData.accel[1] / sqrt(pow(imuData.accel[0], 2) + pow(imuData.accel[2], 2))) * 180 / PI) - AccErrorX;
    accAngleY = (atan(-1 * imuData.accel[0] / sqrt(pow(imuData.accel[1], 2) + pow(imuData.accel[2], 2))) * 180 / PI) - AccErrorY;
    
    // Read gyroscope data
    previousTime = currentTime;
    currentTime = millis();
    elapsedTime = (currentTime - previousTime) / 1000.0;  // Convert to seconds
    
    Wire.beginTransmission(MPU);
    Wire.write(0x43);  // Gyro data first register address
    Wire.endTransmission(false);
    Wire.requestFrom(MPU, 6, true);
    
    // Convert raw values to degrees per second and apply error correction
    imuData.gyro[0] = (Wire.read() << 8 | Wire.read()) / 131.0 - GyroErrorX;
    imuData.gyro[1] = (Wire.read() << 8 | Wire.read()) / 131.0 - GyroErrorY;
    imuData.gyro[2] = (Wire.read() << 8 | Wire.read()) / 131.0 - GyroErrorZ;
    
    // Convert gyro to radians/s
    imuData.gyro[0] *= PI / 180.0;
    imuData.gyro[1] *= PI / 180.0;
    imuData.gyro[2] *= PI / 180.0;
    
    // Calculate gyro angles
    gyroAngleX = gyroAngleX + imuData.gyro[0] * elapsedTime;
    gyroAngleY = gyroAngleY + imuData.gyro[1] * elapsedTime;
    yaw = yaw + imuData.gyro[2] * elapsedTime;
    
    // Complementary filter - combine accelerometer and gyro angle values
    roll = 0.96 * gyroAngleX + 0.04 * accAngleX;
    pitch = 0.96 * gyroAngleY + 0.04 * accAngleY;
    
    // Update IMU orientation data
    imuData.orientation[0] = roll * PI / 180.0;  // Convert to radians
    imuData.orientation[1] = pitch * PI / 180.0;
    imuData.orientation[2] = yaw;
    
    // Update estimated position based on IMU data
    float linear_accel = sqrt(imuData.accel[0] * imuData.accel[0] + 
                             imuData.accel[1] * imuData.accel[1]);
    
    // Zero-velocity update (ZUPT) when acceleration is low and no movement
    if (linear_accel <= 0.25 && 
        abs(estimatedPosition.l_speed) < 0.001 && 
        abs(estimatedPosition.r_speed) < 0.001) {
        estimatedPosition.linear_accel = 0;
        estimatedPosition.linear_velocity = 0;
    } else {
        // Update velocity and position based on acceleration
        estimatedPosition.linear_velocity += linear_accel * elapsedTime;
        estimatedPosition.position[0] += estimatedPosition.orientation[0] * 
                                       estimatedPosition.linear_velocity * elapsedTime;
        estimatedPosition.position[1] += estimatedPosition.orientation[1] * 
                                       estimatedPosition.linear_velocity * elapsedTime;
    }
    
    // Update orientation vector
    float x = estimatedPosition.orientation[0];
    float y = estimatedPosition.orientation[1];
    estimatedPosition.orientation[0] = x*cos(imuData.gyro[2] * elapsedTime) - y*sin(imuData.gyro[2] * elapsedTime);
    estimatedPosition.orientation[1] = x*sin(imuData.gyro[2] * elapsedTime) + y*cos(imuData.gyro[2] * elapsedTime);
    
    // Update azimuth (yaw)
    estimatedPosition.azimuth = yaw;
    
    // Update turn rate
    estimatedPosition.turn_rate = imuData.gyro[2];
    
    lastIMUTime = currentTime;
}

// Function to update limit switch states
void updateLimitSwitches() {
    if (espSerial.available()) {
        String line = espSerial.readStringUntil('\n');
        
        // Convert characters directly to boolean values
        LFO = (int) line[0] - '0' == 1 ? true : false;  // Convert char to int
        RFI = (int) line[1] - '0' == 1 ? true : false;
        RFO = (int) line[2] - '0' == 1 ? true : false;
        LBO = (int) line[3] - '0' == 1 ? true : false;
        LFI = (int) line[4] - '0' == 1 ? true : false;
        RBO = (int) line[5] - '0' == 1 ? true : false;
        LBI = (int) line[6] - '0' == 1 ? true : false;
        RBI = (int) line[7] - '0' == 1 ? true : false;
    }
}

//add aidans encoder velocity processing
void encoderISR_L() {
    unsigned long currentTime = millis(); // get current time
    long timeBetween = currentTime - previousTimeL; // find delta T, only internal and don't update the global
    short stepL = 0; // define current step
  
    // if the time between is too short, act as software debounce and reject the input
    if (timeBetween < MIN_TIME) {
      return;
    }
    // Handle ghost backwards inputs
    if (digitalRead(ENCODER_L_B) != digitalRead(ENCODER_L_A)) {
      stepL = 1; // Invert these for the right
    }
  
    else {
      stepL = -1;
    }
  
    // Set previous time to current time, update global timeBetweenL
    timeBetweenL = timeBetween;
    previousTimeL = currentTime;  
  
    // Handle immediate reversal (first reading)
    if (prevStepL == 0) {
        prevStepL = stepL;
        return;
    }
      
    // Handle zero-crossing
    // (if the sign of the direction changes, assume the new current velocity is zero)
    if ((prevStepL != 0) && (prevStepL == -stepL)) {
        leftEncoderVelocity = 0;
        prevStepL = stepL;
        return;
    }
    // Handle complete step
    if (stepL != 0) {
        leftEncoderVelocity = 1000 * stepL * MIN_ANGLE / timeBetweenL;
        prevStepL = stepL;
    }
    return;
}
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

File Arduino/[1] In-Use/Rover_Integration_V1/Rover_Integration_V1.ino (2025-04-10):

#include <Wire.h>
#include <SoftwareSerial.h>

SoftwareSerial espSerial(A0, 255);  // RX = A0, TX unused

// MPU6050 variables
const int MPU = 0x68;
float AccX, AccY, AccZ, GyroX, GyroY, GyroZ;
float accAngleX, accAngleY, gyroAngleX, gyroAngleY, gyroAngleZ;
float roll, pitch, yaw;
float elapsedTime, currentTime, previousTime;
float GyroErrorX, GyroErrorY, GyroErrorZ;
int c = 0;

// Sensors
bool LFO, RFI, RFO, LBO, LFI, RBO, LBI, RBI;

// Motor and encoder pins
#define CLK1 2
#define DT1 A2
#define CLK2 3
#define DT2 A3
#define IN1 4
#define IN2 A1
#define IN3 8
#define IN4 7
#define EN_A 5
#define EN_B 6

#define CleaningEN 0

int baseSpeedA = 200;
int baseSpeedB = 240;
volatile int encoderValue1 = 0;
volatile int encoderValue2 = 0;
int lastStateCLK1, lastStateCLK2;

// PID control variables
float yawTarget = 0.0;
float Kp = 3.0;

// Perimeter tracking variables
enum PerimeterState {
  FOLLOW_EDGE,
  TURN_AT_CORNER,
  COMPLETE
};

PerimeterState currentState = FOLLOW_EDGE;
int cornerCount = 0;
const int MAX_CORNERS = 4;  // Assuming rectangular surface
float initialYaw = 0.0;
bool firstCornerFound = false;
unsigned long turnStartTime = 0;
const unsigned long TURN_DURATION = 8000;  // ms for 90-degree turn

void setup() {
  //Serial.begin(115200);
  espSerial.begin(38400);

  setupMPU();
  calculate_IMU_error();

  pinMode(CLK1, INPUT); pinMode(DT1, INPUT);
  pinMode(CLK2, INPUT); pinMode(DT2, INPUT);
  attachInterrupt(digitalPinToInterrupt(CLK1), readEncoder1, CHANGE);
  attachInterrupt(digitalPinToInterrupt(CLK2), readEncoder2, CHANGE);

  pinMode(IN1, OUTPUT); pinMode(IN2, OUTPUT);
  pinMode(IN3, OUTPUT); pinMode(IN4, OUTPUT);
  pinMode(EN_A, OUTPUT); pinMode(EN_B, OUTPUT);
  pinMode(CleaningEN, OUTPUT);  // Initialize cleaning motor enable pin
  
  // Store initial yaw for perimeter completion detection
  delay(1000);  // Wait for IMU to stabilize
  updateIMU();
  initialYaw = yaw;
  
 
  Serial.println("Cleaning brushes activated");
  Serial.println("Perimeter tracking initialized");
}

void loop() {
  updateIMU();

  if (espSerial.available()) {
    String line = espSerial.readStringUntil('\n');

    LFI = line[0] - '0';
    RFI = line[1] - '0';
    RFO = line[2] - '0';
    LBO = line[3] - '0';
    LFO = line[4] - '0';
    RBO = line[5] - '0';
    LBI = line[6] - '0';
    RBI = line[7] - '0';

    //Serial.println(String(LFI) + String(RFI) + String(RFO) + String(LBO) + String(LFO) + String(RBO) + String(LBI) + String(RBI));

    // State machine for perimeter tracking
    switch (currentState) {
      case FOLLOW_EDGE:
        followEdge();
         // Turn on cleaning brushes at the end of setup
        digitalWrite(CleaningEN, HIGH);
        break;
        
      case TURN_AT_CORNER:
        turnAtCorner();
         // Turn on cleaning brushes at the end of setup
        digitalWrite(CleaningEN, LOW);
        break;
        
      case COMPLETE:
        // Perimeter complete, stop motors and turn off cleaning brushes
        stop();
        digitalWrite(CleaningEN, LOW);
        Serial.println("PERIMETER COMPLETE! Cleaning brushes deactivated.");
        break;
    }
  }

  printEncoders();
}

void followEdge() {
  // Corner detection - when both left front switches go off
  if (RFO == 0 && RFI == 0) {
    Serial.println("CORNER DETECTED!");
    stop();
    delay(100);
    moveReverse();
    delay(500);
    
    // Check if we've completed a full circuit
    if (cornerCount >= MAX_CORNERS) {
      // Check if we're close to our starting orientation
      float yawDiff = abs(yaw - initialYaw);
      if (yawDiff < 0.5 || yawDiff > (2 * PI - 0.5)) {
        currentState = COMPLETE;
        return;
      }
    }
    
    // Start turning at corner
    currentState = TURN_AT_CORNER;
    turnStartTime = millis();
    cornerCount++;
    // Serial.print("Corner count: ");
    // Serial.println(cornerCount);
  }
  // 🚗 Edge following (left side)
  else if (LFI == 1 && LBI == 1 && LFO == 0 && LBO == 0) {
    yawTarget = yaw;
    moveForwardWithYawControl();
    //Serial.println("STRAIGHT");
  }
  // ↩️ Steer Left
  else if ((LFO == 1 && LFI == 1 && LBO == 1 && LBI == 1) || (LFI == 1 && (LFO == 0 || LFO == 1) && LBI == 0 && LBO == 0)) {
    steerLeft();
    //Serial.println("STEER LEFT");
  }
  // ↪️ Steer Right
  else if (LFO == 0 || LBO == 1) {
    steerRight();
    //Serial.println("STEER RIGHT");
  }
  // ➡️ Default Forward
  else {
    yawTarget = yaw;
    moveForwardWithYawControl();
    //Serial.println("STRAIGHT (DEFAULT)");
  }
}

float angleDifference(float target, float current) {
  float diff = target - current;
  if (diff > PI) diff -= 2 * PI;
  if (diff < -PI) diff += 2 * PI;
  return diff;
}


void turnAtCorner() {
  static bool turnInitialized = false;
  static float targetYaw = 0;

  if (!turnInitialized) {
    targetYaw = yaw + PI / 2.0;
    if (targetYaw > 2 * PI) targetYaw -= 2 * PI;
    turnInitialized = true;

    Serial.print("Target Yaw set to: ");
    Serial.println(targetYaw * 180.0 / PI, 1);
  }

  float yawDiff = abs(angleDifference(targetYaw, yaw));

  Serial.print("Current Yaw: ");
  Serial.print(yaw * 180.0 / PI, 1);
  Serial.print("° | Target: ");
  Serial.print(targetYaw * 180.0 / PI, 1);
  Serial.print("° | Diff: ");
  Serial.print(yawDiff * 180.0 / PI, 1);
  Serial.println("°");

  if (yawDiff > radians(4)) {
    rotateRightBurst();  // perform one burst cycle
  } else {
    stop();
    yawTarget = yaw;
    currentState = FOLLOW_EDGE;
    turnInitialized = false;
    Serial.println("TURN COMPLETE");
  }
}



// ========================== IMU FUNCTIONS ==========================

void setupMPU() {
  Wire.begin();
  Wire.beginTransmission(MPU); Wire.write(0x6B); Wire.write(0x00); Wire.endTransmission(true);
  Wire.beginTransmission(MPU); Wire.write(0x1C); Wire.write(0x10); Wire.endTransmission(true);
  Wire.beginTransmission(MPU); Wire.write(0x1B); Wire.write(0x10); Wire.endTransmission(true);
}

void updateIMU() {
  currentTime = millis();
  elapsedTime = (currentTime - previousTime) / 1000.0;  // in seconds

  Wire.beginTransmission(MPU); Wire.write(0x43); Wire.endTransmission(false);
  Wire.requestFrom(MPU, 6, true);
  GyroX = (Wire.read() << 8 | Wire.read()) / 131.0;
  GyroY = (Wire.read() << 8 | Wire.read()) / 131.0;
  GyroZ = (Wire.read() << 8 | Wire.read()) / 131.0;

  GyroX -= GyroErrorX;
  GyroY -= GyroErrorY;
  GyroZ -= GyroErrorZ;

  if (abs(GyroZ) < 0.5) GyroZ = 0.0;  // ignore small noise


  gyroAngleX += GyroX * elapsedTime;
  gyroAngleY += GyroY * elapsedTime;
  yaw += (GyroZ * elapsedTime) / 5.0;  // Slows down yaw accumulation 3x


  // Normalize yaw
  if (yaw > 2 * PI) yaw -= 2 * PI;
  if (yaw < 0) yaw += 2 * PI;

  previousTime = currentTime;  // 🟢 Move this to the end
}
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

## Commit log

2025-01-20 [rejected] camera edge detection test
2025-01-27 LCD implementation
    [ControllerV1.FCStd]
2025-01-27 added full rover system kicad
    [CleaningSystem.kicad_sch, Complete-Rover-Systems.kicad_pcb, Complete-Rover-Systems.kicad_sch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]
2025-01-27 edge detection fix
    [Complete-Drone-Systems.kicad_pcb, Complete-Drone-Systems.kicad_sch, Complete-Rover-Systems.kicad_sch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]
2025-01-28 Drone Systems schematic all-in-one complete
    [Complete-Drone-Systems.kicad_sch, DronePower.kicad_sch, Flight.kicad_sch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]
2025-01-30 bug fix auto hover
    [Control_V5.ino]
2025-01-31 updated kicads (analog multiplexer)
2025-01-31 bug fix + Service Timer added
    [Control_V5.ino]
2025-02-04 adding structure to components / sensors
2025-02-05 lcd bug fixes + AUX channels enabled
    [Control_V5.ino, Receiver_V5.ino]
2025-02-07 modify indices, gaussian proportional error model
    [testing.py]
2025-02-07 generic error models implemented
    [testing.py]
2025-02-07 Preliminary kalman filter
2025-02-07 IMU testing methods
2025-02-12 Add direct angular acceleration method for motor
2025-02-12 framework visualization options and changed timestep handling
2025-02-12 rover arduino skelly setup
2025-02-13 I've tried a million things I just cannot get this rotary encoder to be accurate
2025-02-13 rotary encoders now working
2025-02-13 Tuned motor PIDs for actual sensor data
2025-02-25 Decent turn rate PID convergence using just sensor data
2025-02-28 Rover IMU component setup
2025-02-28 arduino baseplate compiles
2025-03-01 Updated PID logic, still work to do
2025-03-04 updated rover with imu
    [Complete-Rover-Systems.kicad_sch, EdgeDetection.kicad_sch, IMU.kicad_sch]
2025-03-06 updated arduino rover code to include all concrete actions
2025-03-08 changes to the motor constants
2025-03-09 fixed motors for new gain values -- position PID still broken
    [rover.py, testing.py]
2025-03-10 encoder isr + data processing-> next add actual imu colelction and input pins and output pins
2025-03-14 Inner loop not working yet but in progress, probably won't be done for the presentation tbh
    [rover.py, testing.py]
2025-03-19 compiles, need to verify some logic, still needs correct pin allocation
    [Rover.ino, rover.py]
2025-03-19 updated pin connections
2025-03-20 added imu characterization and including baseline calibration into rover.ino
2025-03-20 updated kicads
    [Complete-Rover-Systems.kicad_sch, PowerSystemRover.kicad_sch]
2025-03-20 updated kicad prints
    [DronePower.kicad_sch]
2025-03-23 new imu
2025-03-26 New method to get readings from the encoders
2025-03-29 reset to auto pid
    [Rover.ino]
